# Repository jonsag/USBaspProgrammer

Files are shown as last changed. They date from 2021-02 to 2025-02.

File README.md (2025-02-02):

# USBaspProgrammer

My adaption of [Thomas Fischl's construction](https://www.fischl.de/usbasp/).  

This README concentrates on using ATmega88, and uploading it with avrisp, with a device such as [this one](https://github.com/jonsag/ardAVRProgrammer).  
Use the ICSP header on the programmer, and remember to set jumper J2.  

## Compile and upload

Put the ATmega88 in the programming device, and  

>$ cd Firmware/firmware

Test avrdude  

>$ make avrdude

    avrdude -c avrisp -p atmega88 -P /dev/ttyUSB0 -b 19200 -v

    avrdude: Version 6.3
            Copyright (c) 2000-2005 Brian Dean, http://www.bdmicro.com/
            Copyright (c) 2007-2014 Joerg Wunsch

            System wide configuration file is "/etc/avrdude.conf"
            User configuration file is "/home/jon/.avrduderc"
            User configuration file does not exist or is not a regular file, skipping

            Using Port                    : /dev/ttyUSB0
            Using Programmer              : avrisp
            Overriding Baud Rate          : 19200
            AVR Part                      : ATmega88
            Chip Erase delay              : 9000 us
            PAGEL                         : PD7
            BS2                           : PC2
            RESET disposition             : dedicated
            RETRY pulse                   : SCK
            serial program mode           : yes
            parallel program mode         : yes
            Timeout                       : 200
            StabDelay                     : 100
            CmdexeDelay                   : 25
            SyncLoops                     : 32
            ByteDelay                     : 0
            PollIndex                     : 3
            PollValue                     : 0x53
            Memory Detail                 :

                                    Block Poll               Page                       Polled
            Memory Type Mode Delay Size  Indx Paged  Size   Size #Pages MinW  MaxW   ReadBack
            ----------- ---- ----- ----- ---- ------ ------ ---- ------ ----- ----- ---------
            eeprom        65    20     4    0 no        512    4      0  3600  3600 0xff 0xff
            flash         65     6    64    0 yes      8192   64    128  4500  4500 0xff 0xff
            lfuse          0     0     0    0 no          1    0      0  4500  4500 0x00 0x00
            hfuse          0     0     0    0 no          1    0      0  4500  4500 0x00 0x00
            efuse          0     0     0    0 no          1    0      0  4500  4500 0x00 0x00
            lock           0     0     0    0 no          1    0      0  4500  4500 0x00 0x00
            calibration    0     0     0    0 no          1    0      0     0     0 0x00 0x00
            signature      0     0     0    0 no          3    0      0     0     0 0x00 0x00

            Programmer Type : STK500
            Description     : Atmel AVR ISP
            Hardware Version: 2
            Firmware Version: 1.18
            Topcard         : Unknown
            Vtarget         : 0.0 V
            Varef           : 0.0 V
            Oscillator      : Off
            SCK period      : 0.1 us

    avrdude: AVR device initialized and ready to accept instructions

    Reading | ################################################## | 100% 0.08s

    avrdude: Device signature = 0x1e930a (probably m88)
    avrdude: safemode: hfuse reads as DF
    avrdude: safemode: efuse reads as F9

    avrdude: safemode: hfuse reads as DF
    avrdude: safemode: efuse reads as F9
    avrdude: safemode: Fuses OK (E:F9, H:DF, L:62)

    avrdude done.  Thank you.

Clean, compile, upload and set fuses  

>$ make clean

    rm -f main.hex main.lst main.obj main.cof main.list main.map main.eep.hex main.bin *.o main.s usbdrv/*.o

>$ make main.hex

    avr-gcc -Wall -O2 -Iusbdrv -I. -mmcu=atmega88  -c usbdrv/usbdrv.c -o usbdrv/usbdrv.o
    avr-gcc -Wall -O2 -Iusbdrv -I. -mmcu=atmega88  -x assembler-with-cpp -c usbdrv/usbdrvasm.S -o usbdrv/usbdrvasm.o
    avr-gcc -Wall -O2 -Iusbdrv -I. -mmcu=atmega88  -c usbdrv/oddebug.c -o usbdrv/oddebug.o
    avr-gcc -Wall -O2 -Iusbdrv -I. -mmcu=atmega88  -c isp.c -o isp.o
    avr-gcc -Wall -O2 -Iusbdrv -I. -mmcu=atmega88  -c clock.c -o clock.o
    avr-gcc -Wall -O2 -Iusbdrv -I. -mmcu=atmega88  -x assembler-with-cpp -c tpi.S -o tpi.o
    avr-gcc -Wall -O2 -Iusbdrv -I. -mmcu=atmega88  -c main.c -o main.o
    avr-gcc -Wall -O2 -Iusbdrv -I. -mmcu=atmega88  -o main.bin usbdrv/usbdrv.o usbdrv/usbdrvasm.o usbdrv/oddebug.o isp.o clock.o tpi.o main.o -Wl,-Map,main.map
    rm -f main.hex main.eep.hex
    avr-objcopy -j .text -j .data -O ihex main.bin main.hex

>$ make flash

    avrdude -c avrisp -p atmega88 -P /dev/ttyUSB0 -b 19200 -U flash:w:main.hex

    avrdude: AVR device initialized and ready to accept instructions

    Reading | ################################################## | 100% 0.08s

    avrdude: Device signature = 0x1e930a (probably m88)
    avrdude: NOTE: "flash" memory has been specified, an erase cycle will be performed
            To disable this feature, specify the -D option.
    avrdude: erasing chip
    avrdude: reading input file "main.hex"
    avrdude: input file main.hex auto detected as Intel Hex
    avrdude: writing flash (4400 bytes):

    Writing | ################################################## | 100% 7.60s

    avrdude: 4400 bytes of flash written
    avrdude: verifying flash memory against main.hex:
    avrdude: load data flash data from input file main.hex:
    avrdude: input file main.hex auto detected as Intel Hex
    avrdude: input file main.hex contains 4400 bytes
    avrdude: reading on-chip flash data:

    Reading | ################################################## | 100% 5.38s

    avrdude: verifying ...
    avrdude: 4400 bytes of flash verified

    avrdude: safemode: Fuses OK (E:F9, H:DF, L:62)

    avrdude done.  Thank you.

>$ make fuses

    avrdude -c avrisp -p atmega88 -P /dev/ttyUSB0 -b 19200 -u -U hfuse:w:0xDD:m -U lfuse:w:0xFF:m

    avrdude: AVR device initialized and ready to accept instructions

    Reading | ################################################## | 100% 0.08s

    avrdude: Device signature = 0x1e930a (probably m88)
    avrdude: reading input file "0xDD"
    avrdude: writing hfuse (1 bytes):

    Writing | ################################################## | 100% 0.09s

    avrdude: 1 bytes of hfuse written
    avrdude: verifying hfuse memory against 0xDD:
    avrdude: load data hfuse data from input file 0xDD:
    avrdude: input file 0xDD contains 1 bytes
    avrdude: reading on-chip hfuse data:

    Reading | ################################################## | 100% 0.03s

    avrdude: verifying ...
    avrdude: 1 bytes of hfuse verified
    avrdude: reading input file "0xFF"
    avrdude: writing lfuse (1 bytes):

    Writing | ################################################## | 100% 0.09s

    avrdude: 1 bytes of lfuse written
    avrdude: verifying lfuse memory against 0xFF:
    avrdude: load data lfuse data from input file 0xFF:
    avrdude: input file 0xFF contains 1 bytes
    avrdude: reading on-chip lfuse data:

    Reading | ################################################## | 100% 0.03s

    avrdude: verifying ...
    avrdude: 1 bytes of lfuse verified

    avrdude done.  Thank you.

## Define device rules

>$ sudo cp \<PATH>/Documents/linux-nonroot/99-USBasp.rules /etc/udev/rules.d/99-USBasp.rules
>
>$ sudo udevadm control --reload-rules

## From Thomas Fischl's README

### USE PRECOMPILED VERSION  

Firmware:  
Flash "Firmware/precompiled/usbasp.atmega88.xxxx-xx-xx.hex" or "Firmware/precompiled/usbaspatmega8.xxxx-xx-xx.hex" to the used controller with a working programmer (e.g. with avrdude, uisp, ...). Set jumper J2 to activate USBasp firmware update function.  
You have to change the fuse bits for external crystal (see "make fuses").  
\# TARGET=atmega8    HFUSE=0xc9  LFUSE=0xef  
\# TARGET=atmega48   HFUSE=0xdd  LFUSE=0xff  
\# TARGET=atmega88   HFUSE=0xdd  LFUSE=0xff  

### Setting jumpers

J1 Power target  
    Supply target with 5V (USB voltage). Be careful with this option, the circuit isn't protected against short circuit!  
J2 Jumper for firmware upgrade (not self-upgradable)  
    Set this jumper for flashing the ATMega(4)8 of USBasp with another working programmer.  
J3 SCK option  
    If the target clock is lower than 1,5 MHz, you have to set this jumper. Then SCK is scaled down from 375 kHz to about 8 kHz  

### BUILDING AND INSTALLING FROM SOURCE CODE

#### Firmware

To compile the firmware  

1. install the GNU toolchain for AVR microcontrollers (avr-gcc, avr-libc),  
2. change directory to Firmware/firmware/  
3. run "make main.hex"  
4. flash "main.hex" to the ATMega(4)8. E.g. with uisp or avrdude (check the Makefile option "make flash"). To flash the firmware you have to set jumper J2 and connect USBasp to a working programmer.  
 You have to change the fuse bits for external crystal, (check the Makefile option "make fuses").  

#### Software (avrdude)

AVRDUDE supports USBasp since version 5.2.  

1. install libusb: [http://libusb.sourceforge.net/](http://libusb.sourceforge.net/)  
2. get latest avrdude release: [http://download.savannah.gnu.org/releases/avrdude/](http://download.savannah.gnu.org/releases/avrdude/)  
3. cd avrdude-X.X.X  
4. configure to your environment:  
./bootstrap (I had to comment out the two if-blocks which verify the installed versions of autoconf and automake)  
./configure  
5. compile and install it:  
make  
make install  

### Notes

To use USBasp as non-root, you have to define some device rules. See Documents/linux-nonroot for an example.  

### MORE INFORMATION

For more information on USBasp and it's components please visit the following URLs:  

USBasp .......................... [http://www.fischl.de/usbasp/](http://www.fischl.de/usbasp/)  
  
Firmware-only V-USB driver ...... [http://www.obdev.at/products/vusb/](http://www.obdev.at/products/vusb/)  
avrdude ......................... [http://www.nongnu.org/avrdude/](http://www.nongnu.org/avrdude/)  
libusb .......................... [http://libusb.sourceforge.net/](http://libusb.sourceforge.net/)  
libusb-win32 .................... [http://libusb-win32.sourceforge.net/](http://libusb-win32.sourceforge.net/)  

## Troubleshooting

### Compiling problem

    usbdrv/usbdrv.h:455:6: error: variable ‘usbDescriptorDevice’ must be const in order to be put into read-only section by means of ‘__attribute__((progmem))’
 char usbDescriptorDevice[];

Solution at [https://openrcforums.com/forum/viewtopic.php?t=2731](https://openrcforums.com/forum/viewtopic.php?t=2731), from Mon Feb 04, 2013  

    This issue is resolved I just wanted to document it here.

    Usbasp uses V-usb for usb communications. Usbasp includes V-usb in it's source code. The version of V-usb included in Usbasp is not the latest and would not compile with a recent avr-gcc. This issue affected er9x over a year ago.

    When trying to compile the 2009 or 2011 versions of Usbasp from http://www.fischl.de/usbasp/ I got about a dozen of these errors.
    CODE: SELECT ALL

    usbdrv/usbdrv.h:451:6: error: variable ‘usbDescriptorDevice’ must be const in order to be put into read-only section by means of ‘__attribute__((progmem))’
    The solution was to remove the ./firmware/usbdrv directory from the Usbasp source and replace it with the source from http://www.obdev.at/downloads/vusb/vusb-20121206.tar.gz . Then I was able to compile Usbasp. I tested both the 2009 and 2011 versions on a programmer and was able to program a MCU.

    Not sure when avr-gcc became picky about this issue or if that is even the issue. Nor do I know why my Ubuntuish 'Linux Mint 14 Nadia' calls the package gcc-avr. Anyway this is what versions of the relevant ( I think) packages I have installed.

    ii avr-libc 1:1.8.0-2 all Standard C library for Atmel AVR developm
    ii binutils-avr 2.20.1-3 amd64 Binary utilities supporting Atmel's AVR t
    ii gcc-avr 1:4.7.0-2 amd64 The GNU C compiler (cross compiler for av

## My notes

Connections on different MCUs  

            10Pin           6pin    ATmega8/88/328/328P     ATtiny4313      ATtiny85  
MOSI    ->  1           ->  4   ->  17/PB3                  17/PB5          5/AREF/PB0  
MISO    ->  9           ->  1   ->  18/PB4                  18/PB6          6/PB1  
SCK     ->  7           ->  3   ->  19/PB5                  19/PB7          7/PB2  
RST     ->  5           ->  5   ->  1/RESET/PC6,21/AREF     1/RESET/PA2     1/RESET/PB5  
VCC     ->  2           ->  2   ->  7/VCC                   20/VCC          8/VCC  
GND     ->  4,6,8,10    ->  6   ->  8/GND                   10/GND          4/GND  
XTAL1                               9/XTAL1                 5/XTAL1         2/XTAL1
XTAL2                               10/XTAL2                4/XTAL2         3/XTAL2

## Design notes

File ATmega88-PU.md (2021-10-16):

# Dissection of the ATmega88-PU

## Empty chip

>$ cu -l /dev/ttyACM0 -s 115200

    Atmega chip detector.
    Written by Nick Gammon.
    Version 1.20
    Compiled on Feb 15 2021 at 16:17:48 with Arduino IDE 10813.
    Attempting to enter ICSP programming mode ...
    Entered programming mode OK.
    Signature = 0x1E 0x93 0x0A 
    Unrecognized signature.
    LFuse = 0x62 
    HFuse = 0xDF 
    EFuse = 0xF9 
    Lock byte = 0xFF 
    Clock calibration = 0xAB 

    First 256 bytes of program memory:

    00: 0xFF 0xFF 0xFF 0xFF 0xFF 0xFF 0xFF 0xFF 0xFF 0xFF 0xFF 0xFF 0xFF 0xFF 0xFF 0xFF
    ...
    F0: 0xFF 0xFF 0xFF 0xFF 0xFF 0xFF 0xFF 0xFF 0xFF 0xFF 0xFF 0xFF 0xFF 0xFF 0xFF 0xFF 

    Programming mode off.

Dumping flash and eeprom  

>$ avrdude -p m88 -P /dev/ttyUSB0 -c avrisp -b 19200 -v -U flash:r:flashEmpty.hex:i -U eeprom:r:eepromEmpty.eep:i

    avrdude: Version 6.3
            Copyright (c) 2000-2005 Brian Dean, http://www.bdmicro.com/
            Copyright (c) 2007-2014 Joerg Wunsch

            System wide configuration file is "/etc/avrdude.conf"
            User configuration file is "/home/jon/.avrduderc"
            User configuration file does not exist or is not a regular file, skipping

            Using Port                    : /dev/ttyUSB0
            Using Programmer              : avrisp
            Overriding Baud Rate          : 19200
            AVR Part                      : ATmega88
            Chip Erase delay              : 9000 us
            PAGEL                         : PD7
            BS2                           : PC2
            RESET disposition             : dedicated
            RETRY pulse                   : SCK
            serial program mode           : yes
            parallel program mode         : yes
            Timeout                       : 200
            StabDelay                     : 100
            CmdexeDelay                   : 25
            SyncLoops                     : 32
            ByteDelay                     : 0
            PollIndex                     : 3
            PollValue                     : 0x53
            Memory Detail                 :

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

            Programmer Type : STK500
            Description     : Atmel AVR ISP
            Hardware Version: 2
            Firmware Version: 1.18
            Topcard         : Unknown
            Vtarget         : 0.0 V
            Varef           : 0.0 V
            Oscillator      : Off
            SCK period      : 0.1 us

    avrdude: AVR device initialized and ready to accept instructions

    Reading | ################################################## | 100% 0.08s

    avrdude: Device signature = 0x1e930a (probably m88)
    avrdude: safemode: hfuse reads as DF
    avrdude: safemode: efuse reads as F9
    avrdude: reading flash memory:

    Reading | ################################################## | 100% 9.97s

    avrdude: Flash is empty, resulting file has no contents.
    avrdude: writing output file "flashEmpty.hex"
    avrdude: reading eeprom memory:

    Reading | ################################################## | 100% 7.88s

    avrdude: writing output file "eepromEmpty.eep"

    avrdude: safemode: hfuse reads as DF
    avrdude: safemode: efuse reads as F9
    avrdude: safemode: Fuses OK (E:F9, H:DF, L:62)

    avrdude done.  Thank you.

Read fuses  

>$ avrdude -p m88 -P /dev/ttyUSB0 -c avrisp -b 19200 -U lfuse:r:-:i -U hfuse:r:-:i -U efuse:r:-:i

    avrdude: AVR device initialized and ready to accept instructions

    Reading | ################################################## | 100% 0.08s

    avrdude: Device signature = 0x1e930a (probably m88)
    avrdude: reading lfuse memory:

    Reading | ################################################## | 100% 0.03s

    avrdude: writing output file "<stdout>"
    :01000000629D
    :00000001FF
    avrdude: reading hfuse memory:

    Reading | ################################################## | 100% 0.03s

    avrdude: writing output file "<stdout>"
    :01000000DF20
    :00000001FF
    avrdude: reading efuse memory:

    Reading | ################################################## | 100% 0.04s

    avrdude: writing output file "<stdout>"
    :01000000F906
    :00000001FF

    avrdude: safemode: Fuses OK (E:F9, H:DF, L:62)

    avrdude done.  Thank you.

All three confirms fuses are  

    LFuse = 0x62 
    HFuse = 0xDF 
    EFuse = 0xF9 

Lock byte  

    Lock byte = 0xFF

Clock calibration  

    Clock calibration = 0xAB

## After programming

>$ cu -l /dev/ttyACM0 -s 115200

    Atmega chip detector.
    Written by Nick Gammon.
    Version 1.20
    Compiled on Feb 15 2021 at 16:17:48 with Arduino IDE 10813.
    Attempting to enter ICSP programming mode ...
    Entered programming mode OK.
    Signature = 0x1E 0x93 0x0A 
    Unrecognized signature.
    LFuse = 0xFF 
    HFuse = 0xDD 
    EFuse = 0xF9 
    Lock byte = 0xFF 
    Clock calibration = 0xAB 

    First 256 bytes of program memory:

    00: 0x42 0xC0 0xAA 0xC1 0x5B 0xC0 0x5A 0xC0 0x59 0xC0 0x58 0xC0 0x57 0xC0 0x56 0xC0 
    ...
    F0: 0x10 0x92 0x28 0x01 0x80 0x91 0x01 0x01 0x84 0xFF 0x3A 0xC0 0xC0 0x91 0x00 0x01 

    Programming mode off.

Dumping flash and eeprom  

>$ avrdude -p m88 -P /dev/ttyUSB0 -c avrisp -b 19200 -v -U flash:r:flashProgrammed.hex:i -U eeprom:r:eepromProgrammed.eep:i

    avrdude: Version 6.3
            Copyright (c) 2000-2005 Brian Dean, http://www.bdmicro.com/
            Copyright (c) 2007-2014 Joerg Wunsch

            System wide configuration file is "/etc/avrdude.conf"
            User configuration file is "/home/jon/.avrduderc"
            User configuration file does not exist or is not a regular file, skipping

            Using Port                    : /dev/ttyUSB0
            Using Programmer              : avrisp
            Overriding Baud Rate          : 19200
            AVR Part                      : ATmega88
            Chip Erase delay              : 9000 us
            PAGEL                         : PD7
            BS2                           : PC2
            RESET disposition             : dedicated
            RETRY pulse                   : SCK
            serial program mode           : yes
            parallel program mode         : yes
            Timeout                       : 200
            StabDelay                     : 100
            CmdexeDelay                   : 25
            SyncLoops                     : 32
            ByteDelay                     : 0
            PollIndex                     : 3
            PollValue                     : 0x53
            Memory Detail                 :

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

            Programmer Type : STK500
            Description     : Atmel AVR ISP
            Hardware Version: 2
            Firmware Version: 1.18
            Topcard         : Unknown
            Vtarget         : 0.0 V
            Varef           : 0.0 V
            Oscillator      : Off
            SCK period      : 0.1 us

    avrdude: AVR device initialized and ready to accept instructions

    Reading | ################################################## | 100% 0.08s

    avrdude: Device signature = 0x1e930a (probably m88)
    avrdude: safemode: hfuse reads as DD
    avrdude: safemode: efuse reads as F9
    avrdude: reading flash memory:

    Reading | ################################################## | 100% 9.97s

    avrdude: writing output file "flashProgrammed.hex"
    avrdude: reading eeprom memory:

    Reading | ################################################## | 100% 7.90s

    avrdude: writing output file "eepromProgrammed.eep"

    avrdude: safemode: hfuse reads as DD
    avrdude: safemode: efuse reads as F9
    avrdude: safemode: Fuses OK (E:F9, H:DD, L:FF)

    avrdude done.  Thank you.

Read fuses  

>$ avrdude -p m88 -P /dev/ttyUSB0 -c avrisp -b 19200 -U lfuse:r:-:i -U hfuse:r:-:i -U efuse:r:-:i

    avrdude: AVR device initialized and ready to accept instructions

    Reading | ################################################## | 100% 0.08s

    avrdude: Device signature = 0x1e930a (probably m88)
    avrdude: reading lfuse memory:

    Reading | ################################################## | 100% 0.03s

    avrdude: writing output file "<stdout>"
    :01000000FF00
    :00000001FF
    avrdude: reading hfuse memory:

    Reading | ################################################## | 100% 0.03s

    avrdude: writing output file "<stdout>"
    :01000000DD22
    :00000001FF
    avrdude: reading efuse memory:

    Reading | ################################################## | 100% 0.03s

    avrdude: writing output file "<stdout>"
    :01000000F906
    :00000001FF

    avrdude: safemode: Fuses OK (E:F9, H:DD, L:FF)

    avrdude done.  Thank you.

All three agrees on fuses  

    LFuse = 0xFF 
    HFuse = 0xDD 
    EFuse = 0xF9 

Lock byte still  

    Lock byte = 0xFF 

Clock calibration is now  

    Clock calibration = 0xAB

Diff  

>$ diff main.hex flashProgrammed.hex | wc -l

    418

## Testing the programmer

Insert programmer  

>$ dmesg

    ...
    [173324.477738] usb 4-4: new low-speed USB device number 32 using ohci-pci
    [173324.722745] usb 4-4: New USB device found, idVendor=16c0, idProduct=05dc, bcdDevice= 1.04
    [173324.722749] usb 4-4: New USB device strings: Mfr=1, Product=2, SerialNumber=0
    [173324.722752] usb 4-4: Product: USBasp
    [173324.722754] usb 4-4: Manufacturer: www.fischl.de

>$ lsusb

    ...
    Bus 004 Device 036: ID 16c0:05dc Van Ooijen Technische Informatica shared ID for use with libusb
    ...

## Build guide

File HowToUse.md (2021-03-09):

# How to use the programmer

Check  

>$ avrdude -p m328p -c usbasp -v

Read flash  

>$ avrdude -p m328p -c usbasp -v -U flash:r:flash.hex:i

Verify flash  

>$ avrdude -p m328p -c usbasp -v -U flash:v:flash.hex:i

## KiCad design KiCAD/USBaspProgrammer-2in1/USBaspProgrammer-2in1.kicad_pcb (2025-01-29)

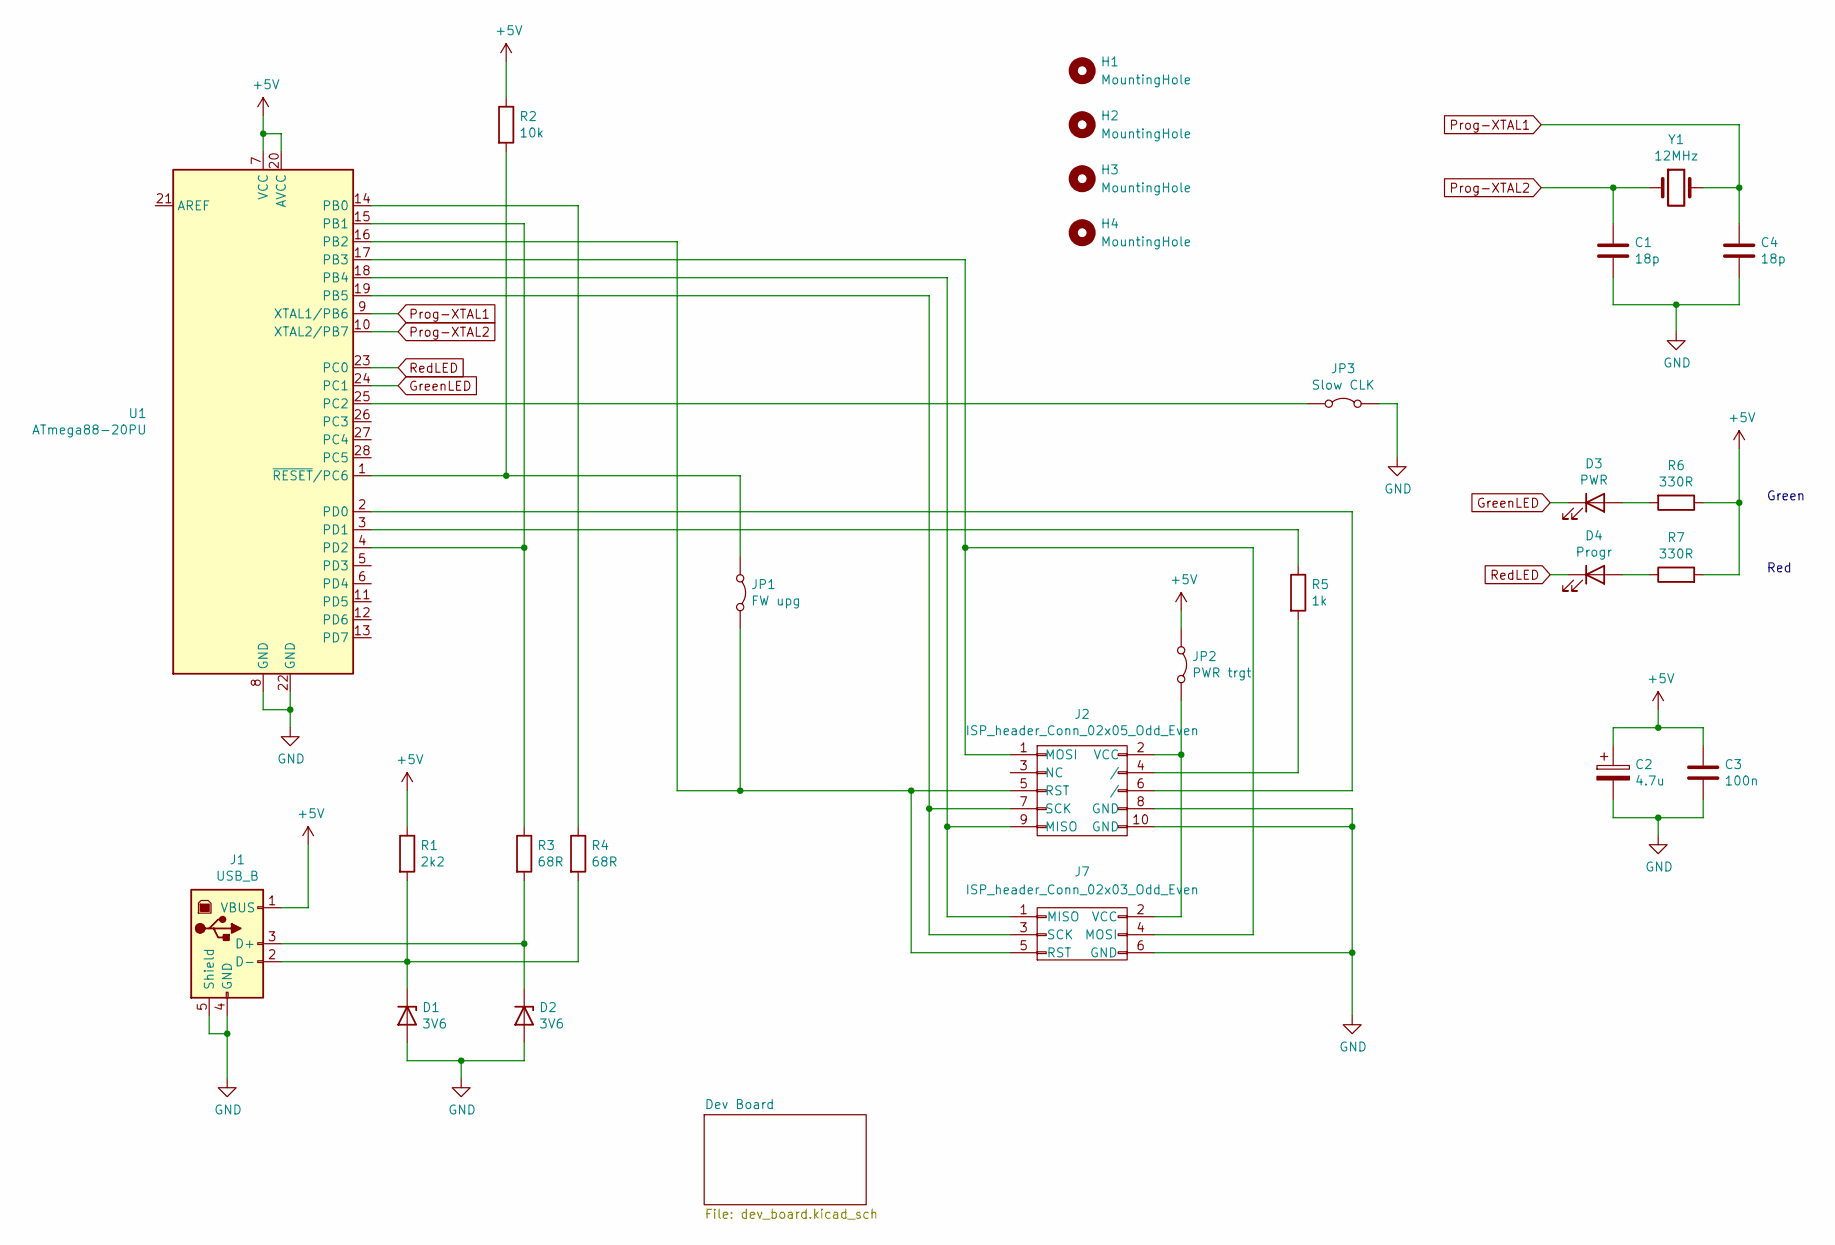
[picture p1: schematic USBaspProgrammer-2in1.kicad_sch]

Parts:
C1, C4: 18p; C_Disc_D3.0mm_W1.6mm_P2.50mm_larg
C2: 4.7u; CP_Radial_D5.0mm_P2.00mm_larger
C3: 100n; C_Disc_D7.5mm_W2.5mm_P5.00mm_larger
D1, D2: 3V6; D_DO-35_SOD27_P7.62mm_Horizontal_large
D3: PWR; LED_D5.0mm_larger_pads
D4: Progr; LED_D5.0mm_larger_pads
H1, H2, H3, H4: MountingHole; MountingHole_3.2mm_M3
J1: USB_B; USB_B_OST_USB-B1HSxx_Horizontal_large
J2: ISP_header_Conn_02x05_Odd_Even; IDC-Header_2x05_P2.54mm_Vertical_large
J7: ISP_header_Conn_02x03_Odd_Even; IDC-Header_2x03_P2.54mm_Horizontal_large
JP1: FW upg; Jumper_1x02_P2.54mm_large
JP2: PWR trgt; Jumper_1x02_P2.54mm_large
JP3: Slow CLK; Jumper_1x02_P2.54mm_large
R1: 2k2; R_Axial_DIN0207_L6.3mm_D2.5mm_P10.16mm_Horizontal_large
R2: 10k; R_Axial_DIN0207_L6.3mm_D2.5mm_P10.16mm_Horizontal_large
R3, R4: 68R; R_Axial_DIN0207_L6.3mm_D2.5mm_P10.16mm_Horizontal_large
R5: 1k; R_Axial_DIN0207_L6.3mm_D2.5mm_P10.16mm_Horizontal_large
R6, R7: 330R; R_Axial_DIN0207_L6.3mm_D2.5mm_P10.16mm_Horizontal_large
U1: ATmega88-20PU; DIP-28_W7.62mm_LongPads w socket
Y1: 12MHz; Crystal_HC49-4H_Vertical_large

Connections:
+5V: C2.1, C3.1, J1.1 (VBUS), JP2.1 (A), R1.1, R2.1, R6.1, R7.2, U1.7 (VCC), U1.20 (AVCC)
GND: C1.2, C2.2, C3.2, C4.2, D1.2 (A), D2.2 (A), J1.4 (GND), J1.5 (Shield), J2.8 (GND), J2.10 (GND), J7.6 (GND), JP3.2 (B), U1.8 (GND), U1.22 (GND); also elsewhere on the board
GreenLED: D3.1 (K), U1.24 (PC1)
unnamed: D1.1 (K), J1.2 (D-), R1.2, R4.2
unnamed: D2.1 (K), J1.3 (D+), R3.2
unnamed: D3.2 (A), R6.2
unnamed: D4.2 (A), R7.1
unnamed: J2.9 (MISO), J7.1 (MISO), U1.18 (PB4)
unnamed: J2.1 (MOSI), J7.4 (MOSI), U1.17 (PB3)
unnamed: J2.5 (RST), J7.5 (RST), JP1.2 (B), U1.16 (PB2)
unnamed: J2.7 (SCK), J7.3 (SCK), U1.19 (PB5)
unnamed: J2.2 (VCC), J7.2 (VCC), JP2.2 (B)
unnamed: J2.4 (/), R5.2
unnamed: JP1.1 (A), R2.2, U1.1 (~RESET/PC6)
unnamed: JP3.1 (A), U1.25 (PC2)
unnamed: R4.1, U1.14 (PB0)
unnamed: R3.1, U1.4 (PD2), U1.15 (PB1)
unnamed: J2.6 (/), U1.2 (PD0)
unnamed: R5.1, U1.3 (PD1)
Prog-XTAL1: C4.1, U1.9 (XTAL1/PB6), Y1.2
Prog-XTAL2: C1.1, U1.10 (XTAL2/PB7), Y1.1
RedLED: D4.1 (K), U1.23 (PC0)

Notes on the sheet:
Green
Red

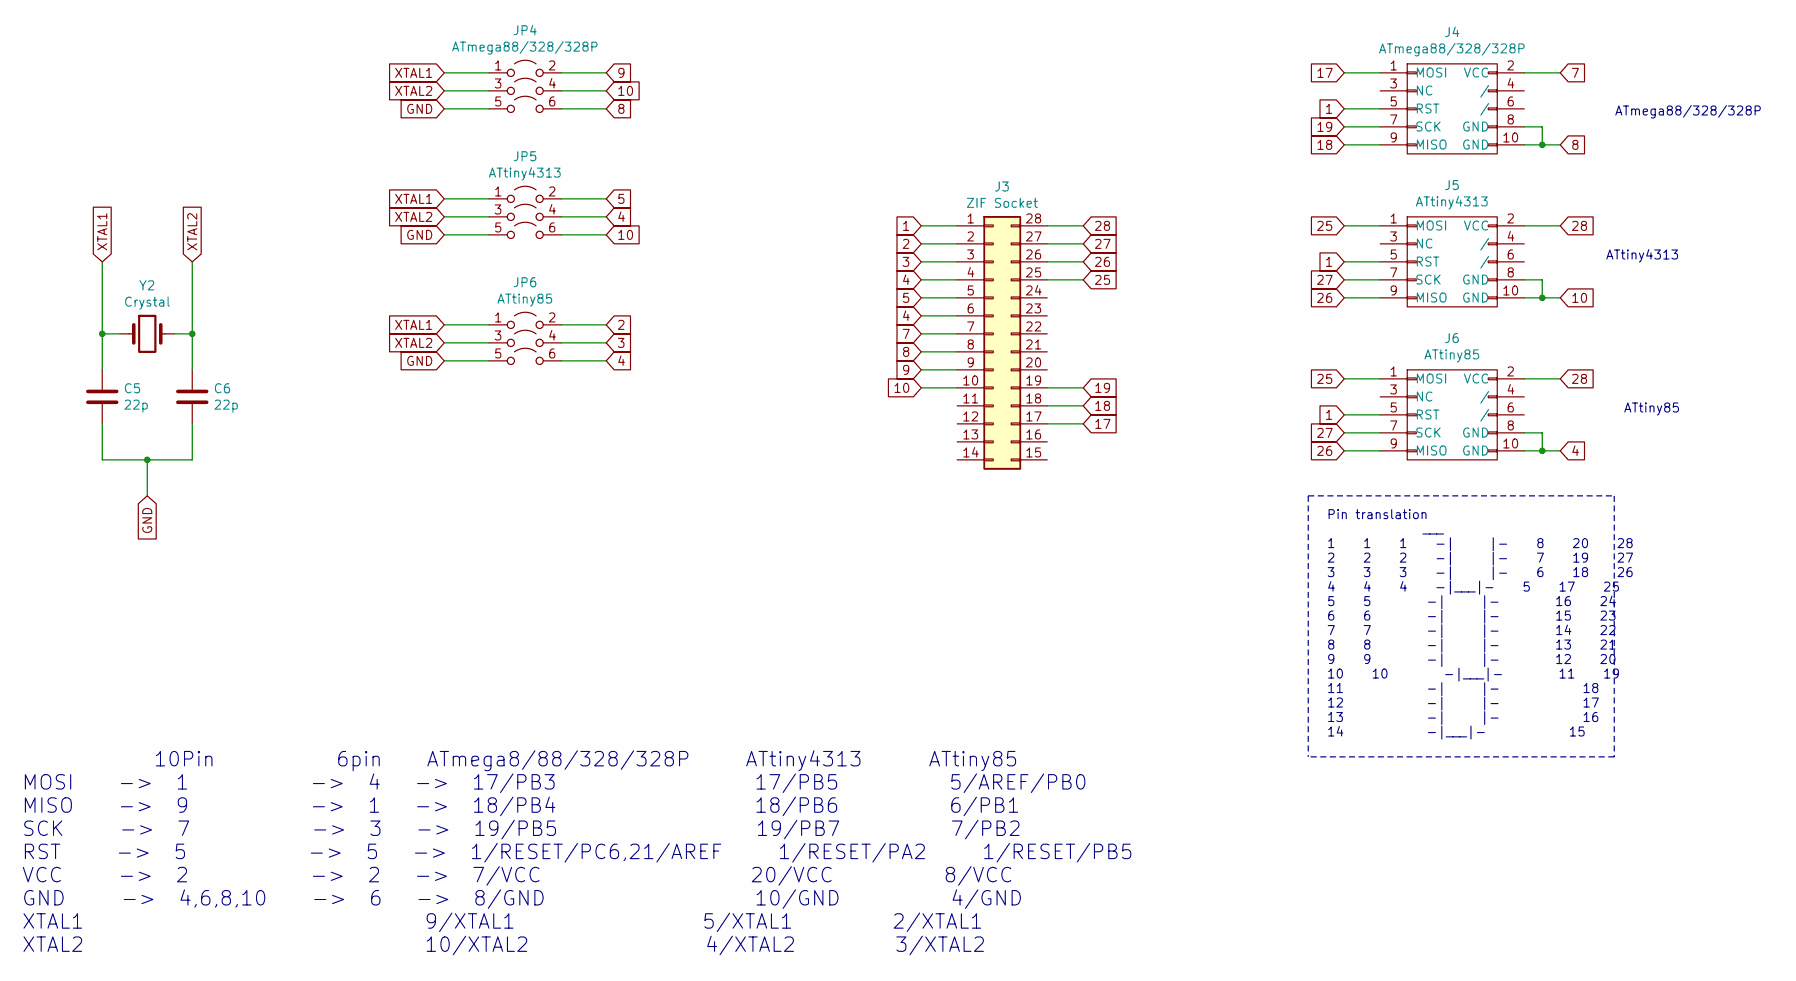
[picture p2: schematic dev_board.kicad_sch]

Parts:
C5, C6: 22p; C_Disc_D3.0mm_W1.6mm_P2.50mm_larg
J3: ZIF Socket; ZIF_DIP_Socket-28_W6.9_W7.62_W7.62_W12.7_W13.5_large
J4: ATmega88/328/328P; IDC-Header_2x05_P2.54mm_Vertical_large
J5: ATtiny4313; IDC-Header_2x05_P2.54mm_Vertical_large
J6: ATtiny85; IDC-Header_2x05_P2.54mm_Vertical_large
JP4: ATmega88/328/328P; 3-pole_jumper_2x03_P2.54mm_Vertical
JP5: ATtiny4313; 3-pole_jumper_2x03_P2.54mm_Vertical
JP6: ATtiny85; 3-pole_jumper_2x03_P2.54mm_Vertical
Y2: Crystal; Crystal_HC49-4H_Vertical_large

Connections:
1: J3.1, J4.5 (RST), J5.5 (RST), J6.5 (RST)
2: J3.2, JP6.2 (B)
3: J3.3, JP6.4
4: J3.4, J3.6, J6.8 (GND), J6.10 (GND), JP5.4, JP6.6
5: J3.5, JP5.2 (B)
7: J3.7, J4.2 (VCC)
8: J3.8, J4.8 (GND), J4.10 (GND), JP4.6
9: J3.9, JP4.2 (B)
10: J3.10, J5.8 (GND), J5.10 (GND), JP4.4, JP5.6
17: J3.17, J4.1 (MOSI)
18: J3.18, J4.9 (MISO)
19: J3.19, J4.7 (SCK)
25: J3.25, J5.1 (MOSI), J6.1 (MOSI)
26: J3.26, J5.9 (MISO), J6.9 (MISO)
27: J3.27, J5.7 (SCK), J6.7 (SCK)
28: J3.28, J5.2 (VCC), J6.2 (VCC)
GND: C5.2, C6.2, JP4.5, JP5.5, JP6.5; also elsewhere on the board
XTAL1: C5.1, JP4.1 (A), JP5.1 (A), JP6.1 (A), Y2.1
XTAL2: C6.1, JP4.3, JP5.3, JP6.3, Y2.2

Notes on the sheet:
ATtiny85
Pin translation ___ 1 1 1 -| |- 8 20 28 2 2 2 -| |- 7 19 27 3 3 3 -| |- 6 18 26 4 4 4 -|___|- 5 17 25 5 5 -| |- 16 24 6 6 -| |- 15 23 7 7 -| |- 14 22 8 8 -| |- 13 21 9 9 -| |- 12 20 10 10 -|___|- 11 19 11 -| |- 18 12 -| |- 17 13 -| |- 16 14 -|___|- 15
ATmega88/328/328P
10Pin 6pin ATmega8/88/328/328P ATtiny4313 ATtiny85 MOSI -> 1 -> 4 -> 17/PB3 17/PB5 5/AREF/PB0 MISO -> 9 -> 1 -> 18/PB4 18/PB6 6/PB1 SCK -> 7 -> 3 -> 19/PB5 19/PB7 7/PB2 RST -> 5 -> 5 -> 1/RESET/PC6,21/AREF 1/RESET/PA2 1/RESET/PB5 VCC -> 2 -> 2 -> 7/VCC 20/VCC 8/VCC GND -> 4,6,8,10 -> 6 -> 8/GND 10/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
ATtiny4313

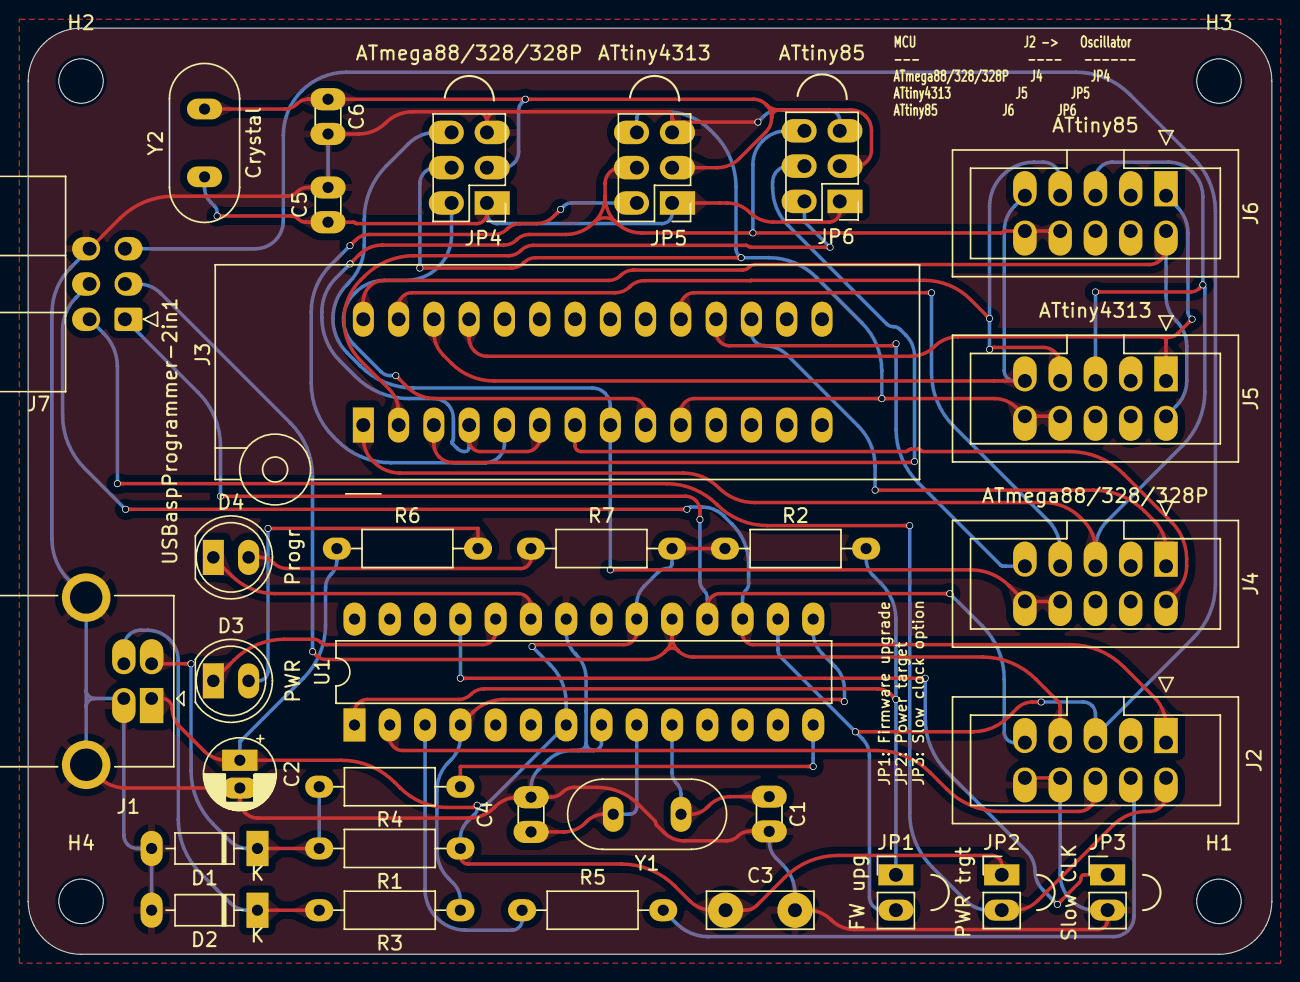
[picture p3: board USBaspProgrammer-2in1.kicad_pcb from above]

Board: 2 copper layers, 89.5 x 66.7 mm, 37 parts (0 on the bottom side), 40 nets.

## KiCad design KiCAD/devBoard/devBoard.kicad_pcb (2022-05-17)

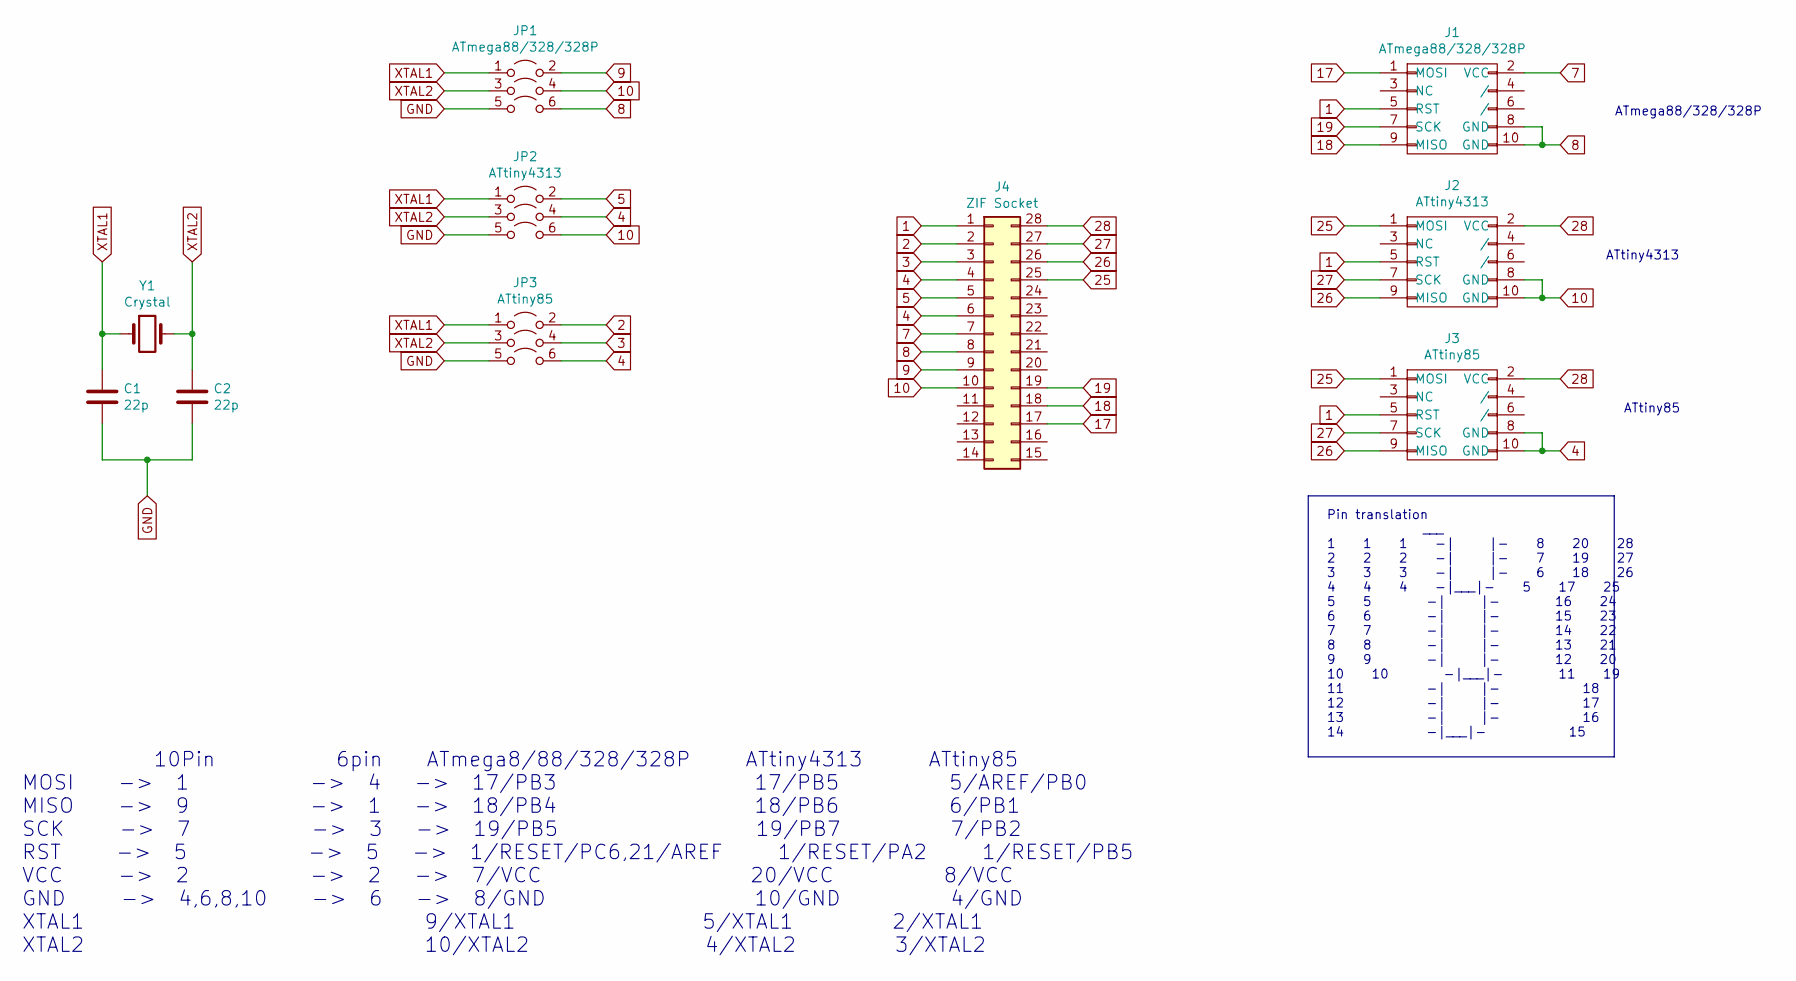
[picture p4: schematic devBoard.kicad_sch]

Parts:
C1, C2: 22p; C_Disc_D3.0mm_W1.6mm_P2.50mm_larg
J1: ATmega88/328/328P; IDC-Header_2x05_P2.54mm_Vertical_large
J2: ATtiny4313; IDC-Header_2x05_P2.54mm_Vertical_large
J3: ATtiny85; IDC-Header_2x05_P2.54mm_Vertical_large
J4: ZIF Socket; ZIF_DIP_Socket-28_W6.9_W7.62_W7.62_W12.7_W13.5_large
JP1: ATmega88/328/328P; 3-pole_jumper_2x03_P2.54mm_Vertical
JP2: ATtiny4313; 3-pole_jumper_2x03_P2.54mm_Vertical
JP3: ATtiny85; 3-pole_jumper_2x03_P2.54mm_Vertical
Y1: Crystal; 2-pin_Crystal_header_large

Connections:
1: J1.5 (RST), J2.5 (RST), J3.5 (RST), J4.1
2: J4.2, JP3.2 (B)
3: J4.3, JP3.4
4: J3.8 (GND), J3.10 (GND), J4.4, J4.6, JP2.4, JP3.6
5: J4.5, JP2.2 (B)
7: J1.2 (VCC), J4.7
8: J1.8 (GND), J1.10 (GND), J4.8, JP1.6
9: J4.9, JP1.2 (B)
10: J2.8 (GND), J2.10 (GND), J4.10, JP1.4, JP2.6
17: J1.1 (MOSI), J4.17
18: J1.9 (MISO), J4.18
19: J1.7 (SCK), J4.19
25: J2.1 (MOSI), J3.1 (MOSI), J4.25
26: J2.9 (MISO), J3.9 (MISO), J4.26
27: J2.7 (SCK), J3.7 (SCK), J4.27
28: J2.2 (VCC), J3.2 (VCC), J4.28
GND: C1.2, C2.2, JP1.5, JP2.5, JP3.5
XTAL1: C1.1, JP1.1 (A), JP2.1 (A), JP3.1 (A), Y1.1
XTAL2: C2.1, JP1.3, JP2.3, JP3.3, Y1.2

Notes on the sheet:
ATtiny4313
ATmega88/328/328P
ATtiny85
Pin translation ___ 1 1 1 -| |- 8 20 28 2 2 2 -| |- 7 19 27 3 3 3 -| |- 6 18 26 4 4 4 -|___|- 5 17 25 5 5 -| |- 16 24 6 6 -| |- 15 23 7 7 -| |- 14 22 8 8 -| |- 13 21 9 9 -| |- 12 20 10 10 -|___|- 11 19 11 -| |- 18 12 -| |- 17 13 -| |- 16 14 -|___|- 15
10Pin 6pin ATmega8/88/328/328P ATtiny4313 ATtiny85 MOSI -> 1 -> 4 -> 17/PB3 17/PB5 5/AREF/PB0 MISO -> 9 -> 1 -> 18/PB4 18/PB6 6/PB1 SCK -> 7 -> 3 -> 19/PB5 19/PB7 7/PB2 RST -> 5 -> 5 -> 1/RESET/PC6,21/AREF 1/RESET/PA2 1/RESET/PB5 VCC -> 2 -> 2 -> 7/VCC 20/VCC 8/VCC GND -> 4,6,8,10 -> 6 -> 8/GND 10/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

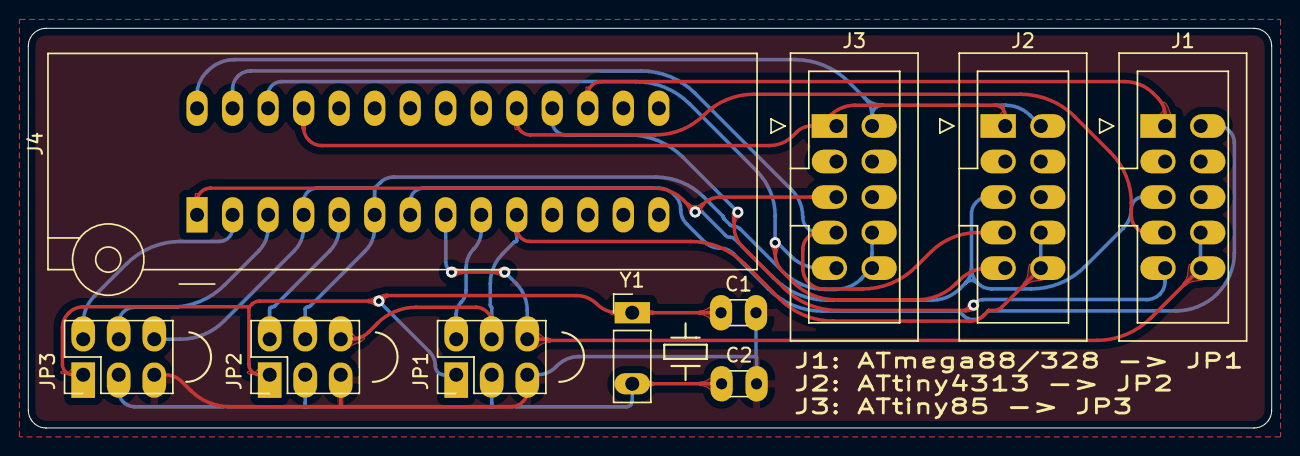
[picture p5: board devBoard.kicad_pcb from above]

Board: 2 copper layers, 88.9 x 28.6 mm, 10 parts (0 on the bottom side), 19 nets.

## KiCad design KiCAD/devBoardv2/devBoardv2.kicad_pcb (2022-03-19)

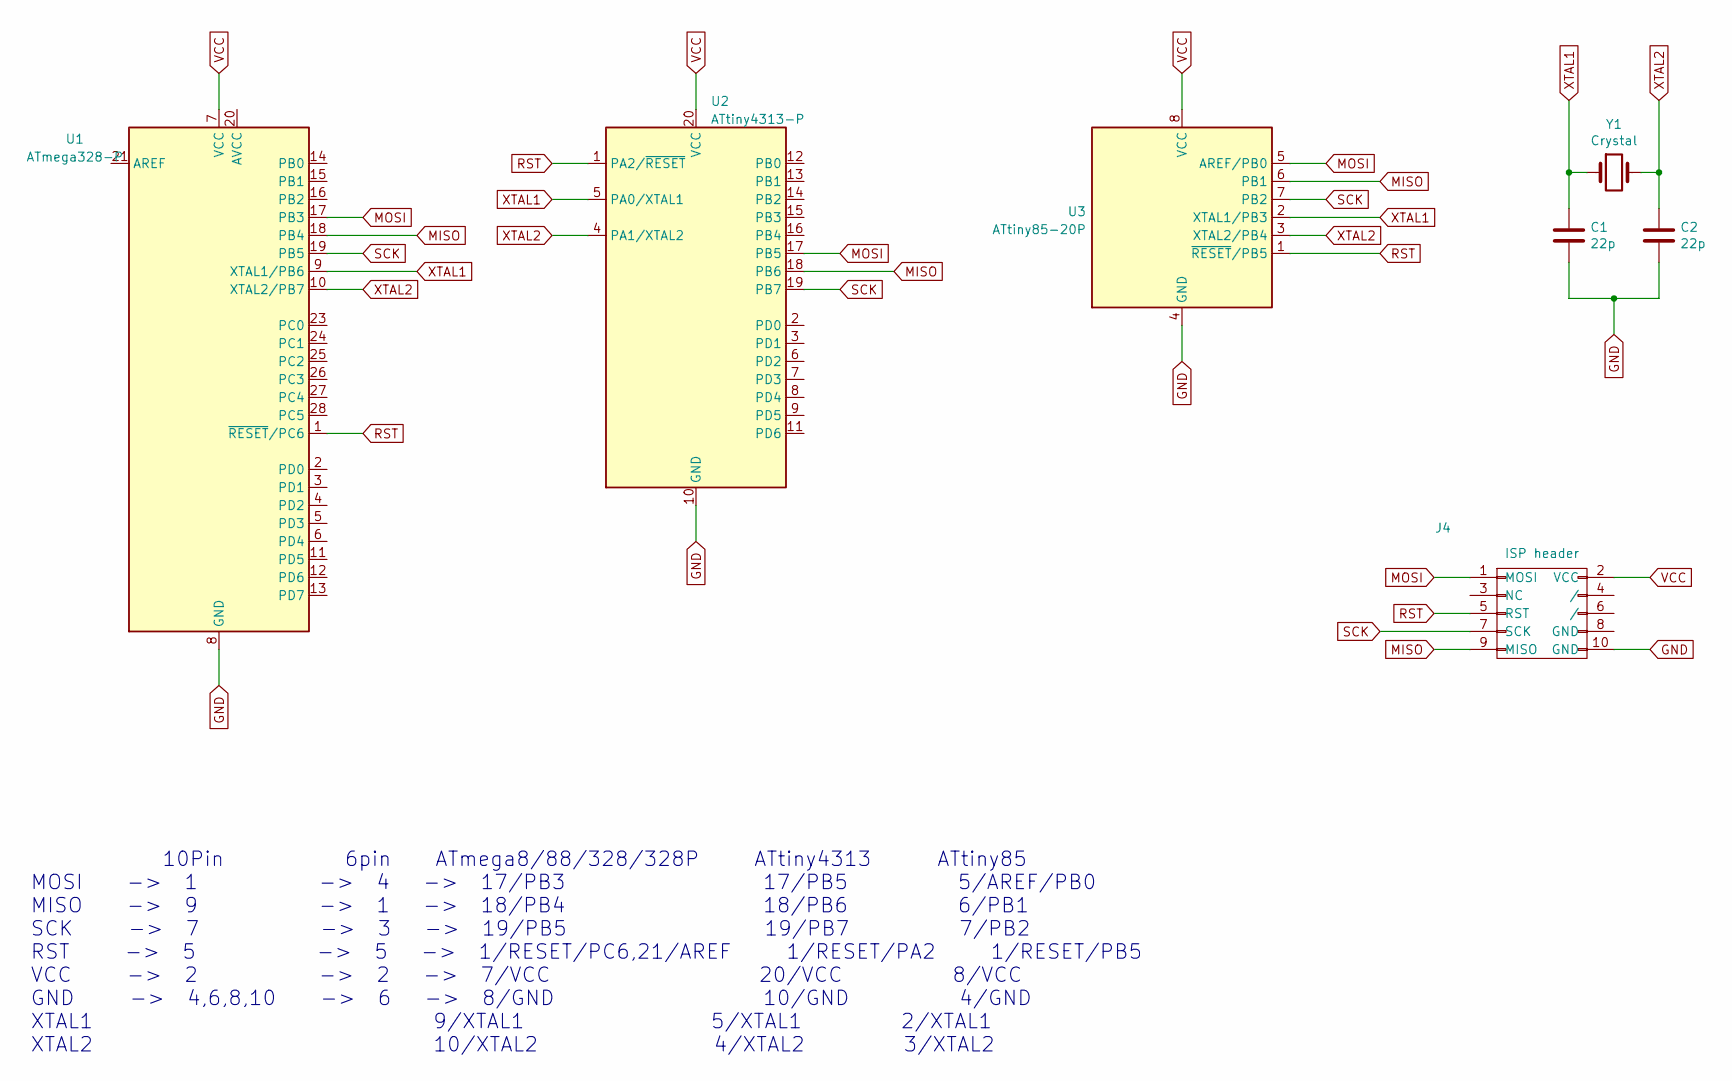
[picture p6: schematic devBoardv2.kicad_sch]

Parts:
C1, C2: 22p; C_Disc_D3.0mm_W1.6mm_P2.50mm_larg
J4: ISP header; IDC-Header_2x05_P2.54mm_Vertical_large
U1: ATmega328-P
U2: ATtiny4313-P
U3: ATtiny85-20P
Y1: Crystal; 2-pin_Crystal_header_large

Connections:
GND: C1.2, C2.2, J4.10 (GND), U1.8 (GND), U1.22 (GND), U2.10 (GND), U3.4 (GND)
MISO: J4.9 (MISO), U1.18 (PB4), U2.18 (PB6), U3.6 (PB1)
MOSI: J4.1 (MOSI), U1.17 (PB3), U2.17 (PB5), U3.5 (AREF/PB0)
RST: J4.5 (RST), U1.1 (~RESET/PC6), U2.1 (PA2/~RESET), U3.1 (~RESET/PB5)
SCK: J4.7 (SCK), U1.19 (PB5), U2.19 (PB7), U3.7 (PB2)
VCC: J4.2 (VCC), U1.7 (VCC), U2.20 (VCC), U3.8 (VCC)
XTAL1: C1.1, U1.9 (XTAL1/PB6), U2.5 (PA0/XTAL1), U3.2 (XTAL1/PB3), Y1.1
XTAL2: C2.1, U1.10 (XTAL2/PB7), U2.4 (PA1/XTAL2), U3.3 (XTAL2/PB4), Y1.2

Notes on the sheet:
10Pin 6pin ATmega8/88/328/328P ATtiny4313 ATtiny85 MOSI -> 1 -> 4 -> 17/PB3 17/PB5 5/AREF/PB0 MISO -> 9 -> 1 -> 18/PB4 18/PB6 6/PB1 SCK -> 7 -> 3 -> 19/PB5 19/PB7 7/PB2 RST -> 5 -> 5 -> 1/RESET/PC6,21/AREF 1/RESET/PA2 1/RESET/PB5 VCC -> 2 -> 2 -> 7/VCC 20/VCC 8/VCC GND -> 4,6,8,10 -> 6 -> 8/GND 10/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

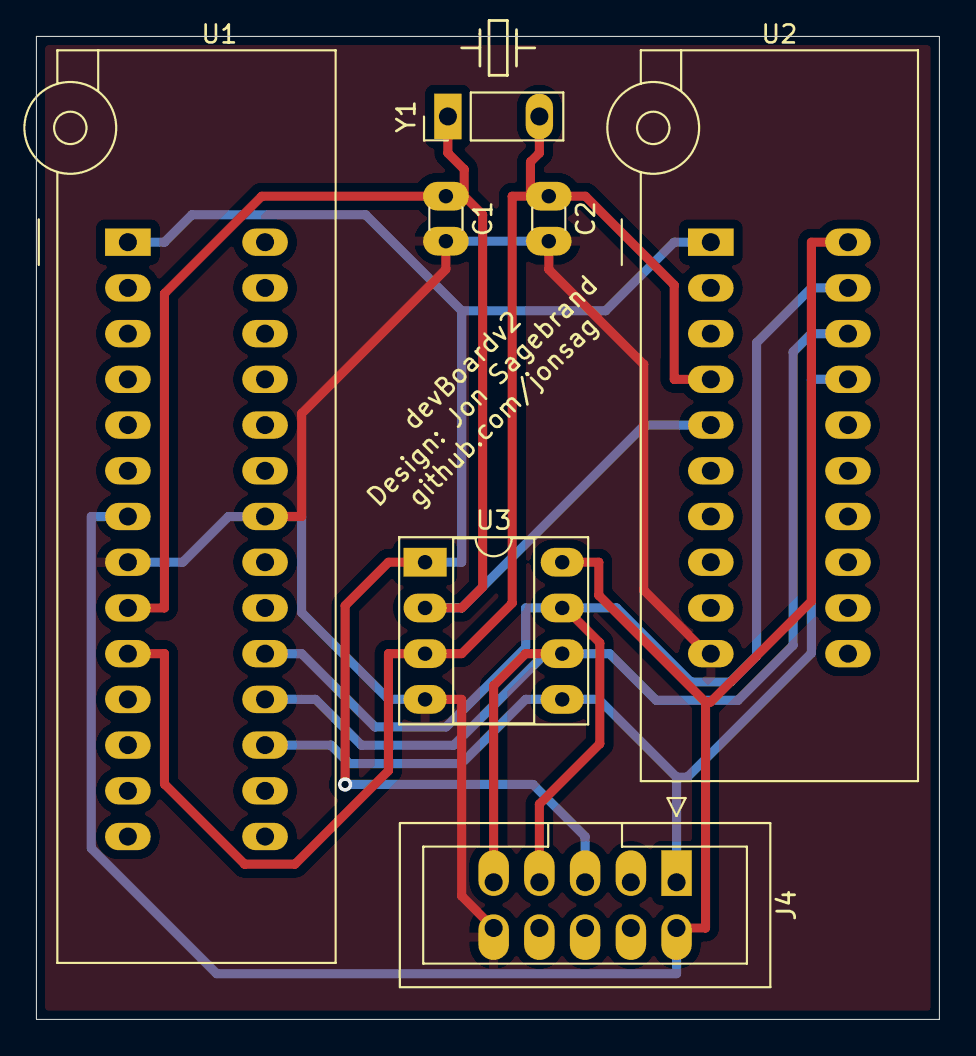
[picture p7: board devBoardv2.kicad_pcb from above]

Board: 2 copper layers, 50.2 x 54.6 mm, 7 parts (0 on the bottom side), 8 nets.

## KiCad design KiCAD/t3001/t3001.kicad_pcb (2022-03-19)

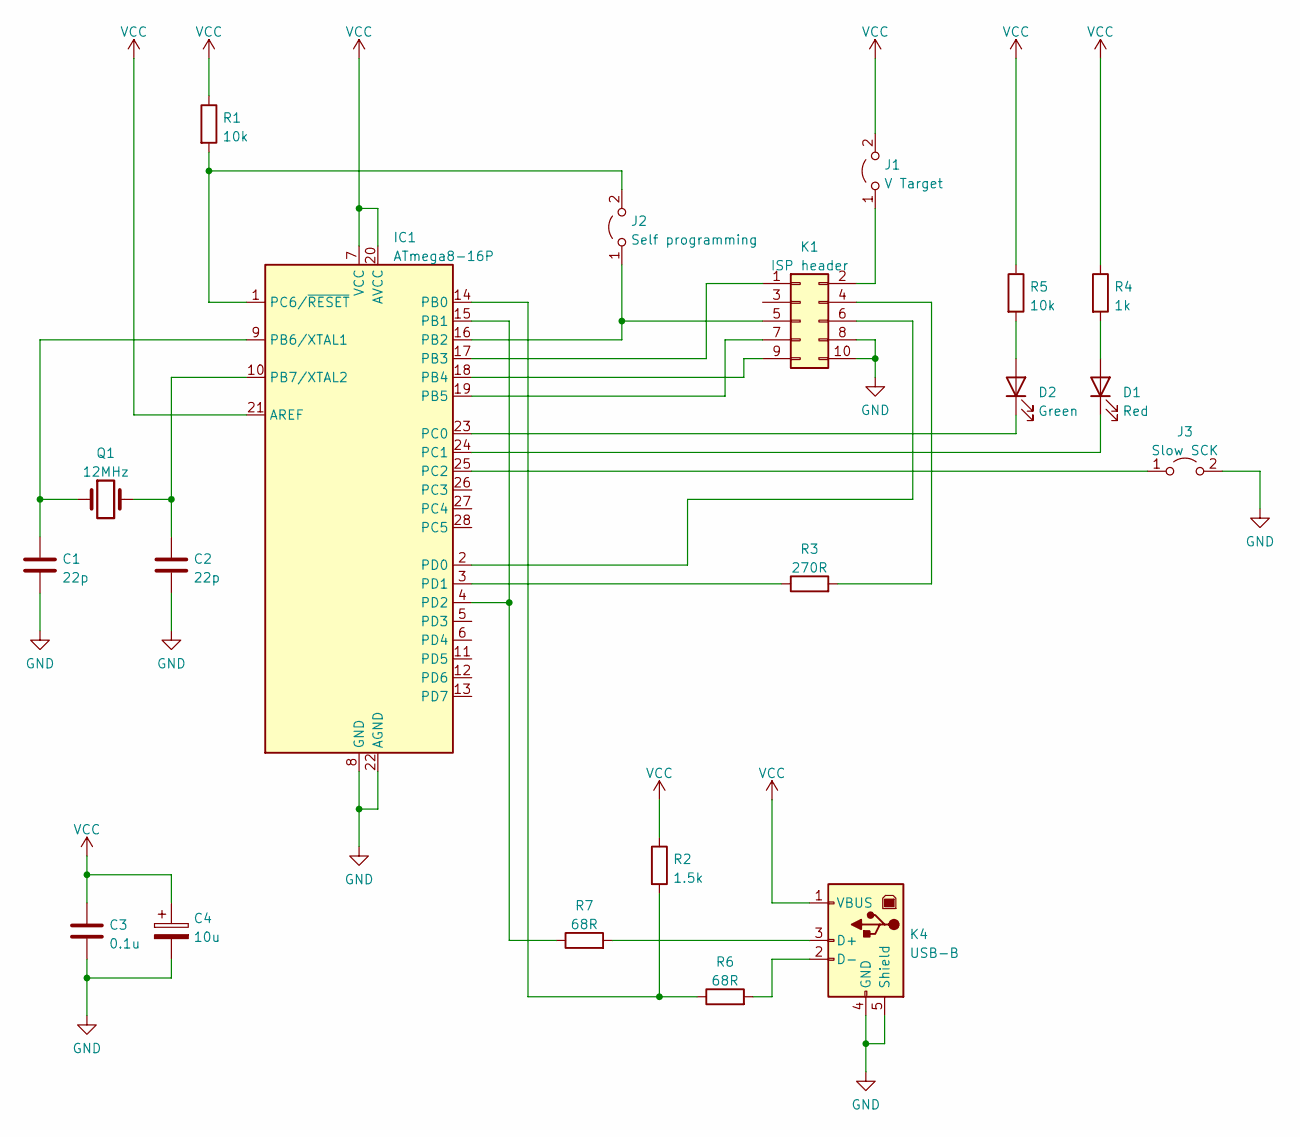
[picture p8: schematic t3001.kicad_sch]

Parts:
C1, C2: 22p; C_Disc_D3.0mm_W1.6mm_P2.50mm_larg
C3: 0.1u; C_Disc_D3.0mm_W1.6mm_P2.50mm_larg
C4: 10u; CP_Radial_D5.0mm_P2.50mm_larger_pads
D1: Red; LED_D5.0mm_larger_pads
D2: Green; LED_D5.0mm_larger_pads
IC1: ATmega8-16P; DIP-28_W7.62mm_LongPads
J1: V Target; Jumper_1x02_P2.54mm_large
J2: Self programming; Jumper_1x02_P2.54mm_large
J3: Slow SCK; Jumper_1x02_P2.54mm_large
K1: ISP header; 2x5_ISP_header_large
K4: USB-B; USB_B_OST_USB-B1HSxx_Horizontal_large
Q1: 12MHz; Crystal_HC49-4H_Vertical_large
R1, R5: 10k; R_Axial_DIN0207_L6.3mm_D2.5mm_P10.16mm_Horizontal_larger_pa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
R2: 1.5k; R_Axial_DIN0207_L6.3mm_D2.5mm_P10.16mm_Horizontal_larger_pa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
R3: 270R; R_Axial_DIN0207_L6.3mm_D2.5mm_P10.16mm_Horizontal_larger_pa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
R4: 1k; R_Axial_DIN0207_L6.3mm_D2.5mm_P10.16mm_Horizontal_larger_pa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
R6, R7: 68R; R_Axial_DIN0207_L6.3mm_D2.5mm_P10.16mm_Horizontal_larger_pa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

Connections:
GND: C1.2, C2.2, C3.2, C4.2, IC1.8 (GND), IC1.22 (AGND), J3.2 (B), K1.8, K1.10, K4.4 (GND), K4.5 (Shield)
unnamed: C1.1, IC1.9 (PB6/XTAL1), Q1.1
unnamed: C2.1, IC1.10 (PB7/XTAL2), Q1.2
unnamed: D1.1 (K), IC1.24 (PC1)
unnamed: D1.2 (A), R4.2
unnamed: D2.1 (K), IC1.23 (PC0)
unnamed: D2.2 (A), R5.2
unnamed: IC1.1 (PC6/~RESET), J2.2 (B), R1.2
unnamed: IC1.2 (PD0), K1.6
unnamed: IC1.3 (PD1), R3.1
unnamed: IC1.14 (PB0), R2.2, R6.1
unnamed: IC1.4 (PD2), IC1.15 (PB1), R7.1
unnamed: IC1.16 (PB2), J2.1 (A), K1.5
unnamed: IC1.17 (PB3), K1.1
unnamed: IC1.18 (PB4), K1.9
unnamed: IC1.19 (PB5), K1.7
unnamed: IC1.25 (PC2), J3.1 (A)
unnamed: J1.1 (A), K1.2
unnamed: K1.4, R3.2
unnamed: K4.2 (D-), R6.2
unnamed: K4.3 (D+), R7.2
VCC: C3.1, C4.1, IC1.7 (VCC), IC1.20 (AVCC), IC1.21 (AREF), J1.2 (B), K4.1 (VBUS), R1.1, R2.1, R4.1, R5.1

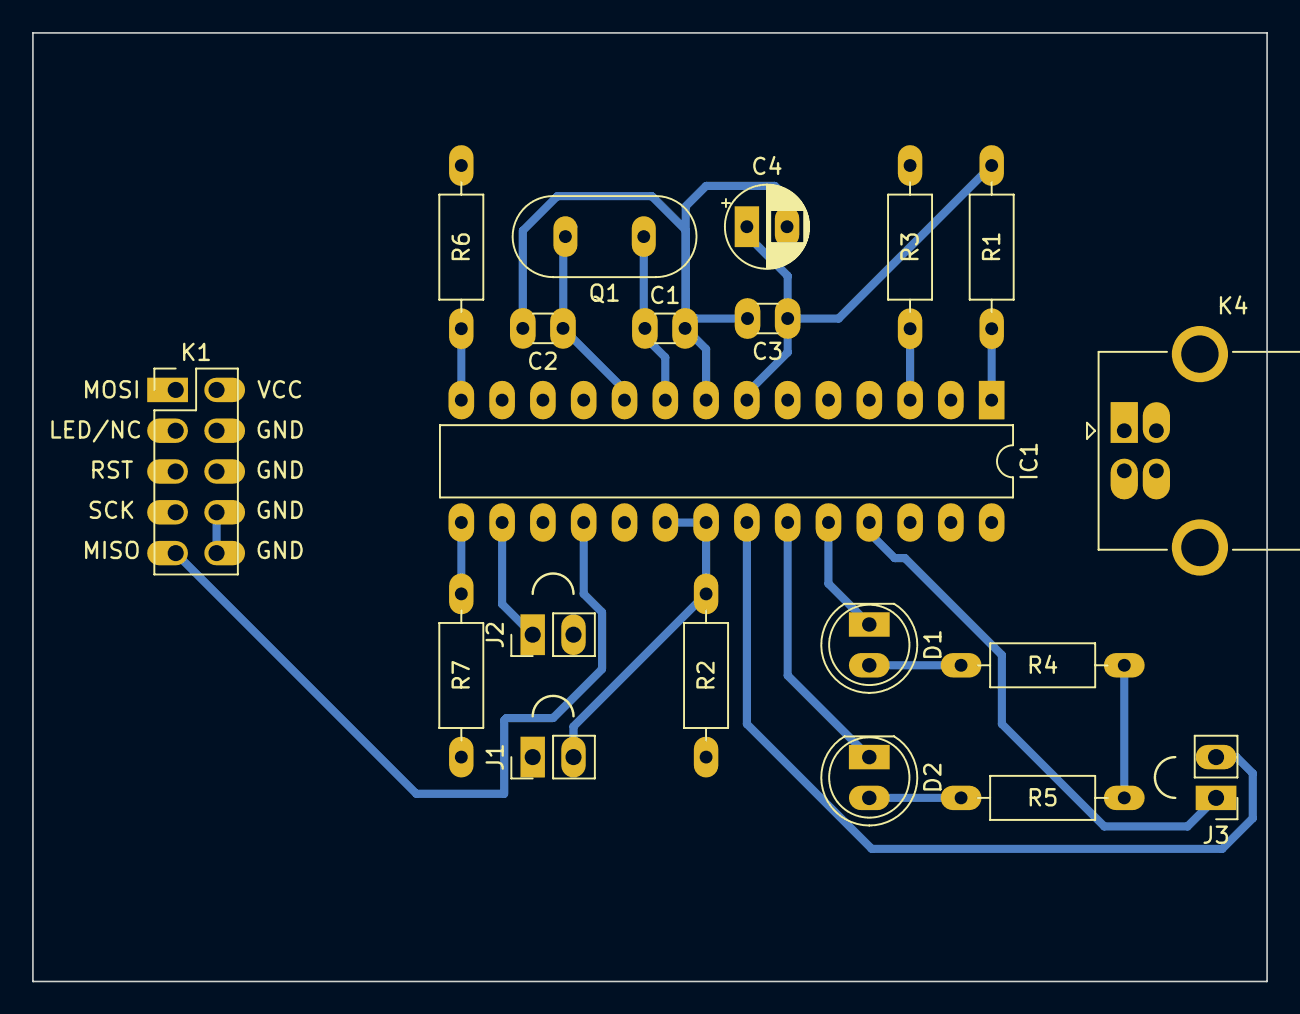
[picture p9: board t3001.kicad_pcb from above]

Board: 2 copper layers, 76.8 x 59.1 mm, 20 parts (0 on the bottom side), 22 nets.

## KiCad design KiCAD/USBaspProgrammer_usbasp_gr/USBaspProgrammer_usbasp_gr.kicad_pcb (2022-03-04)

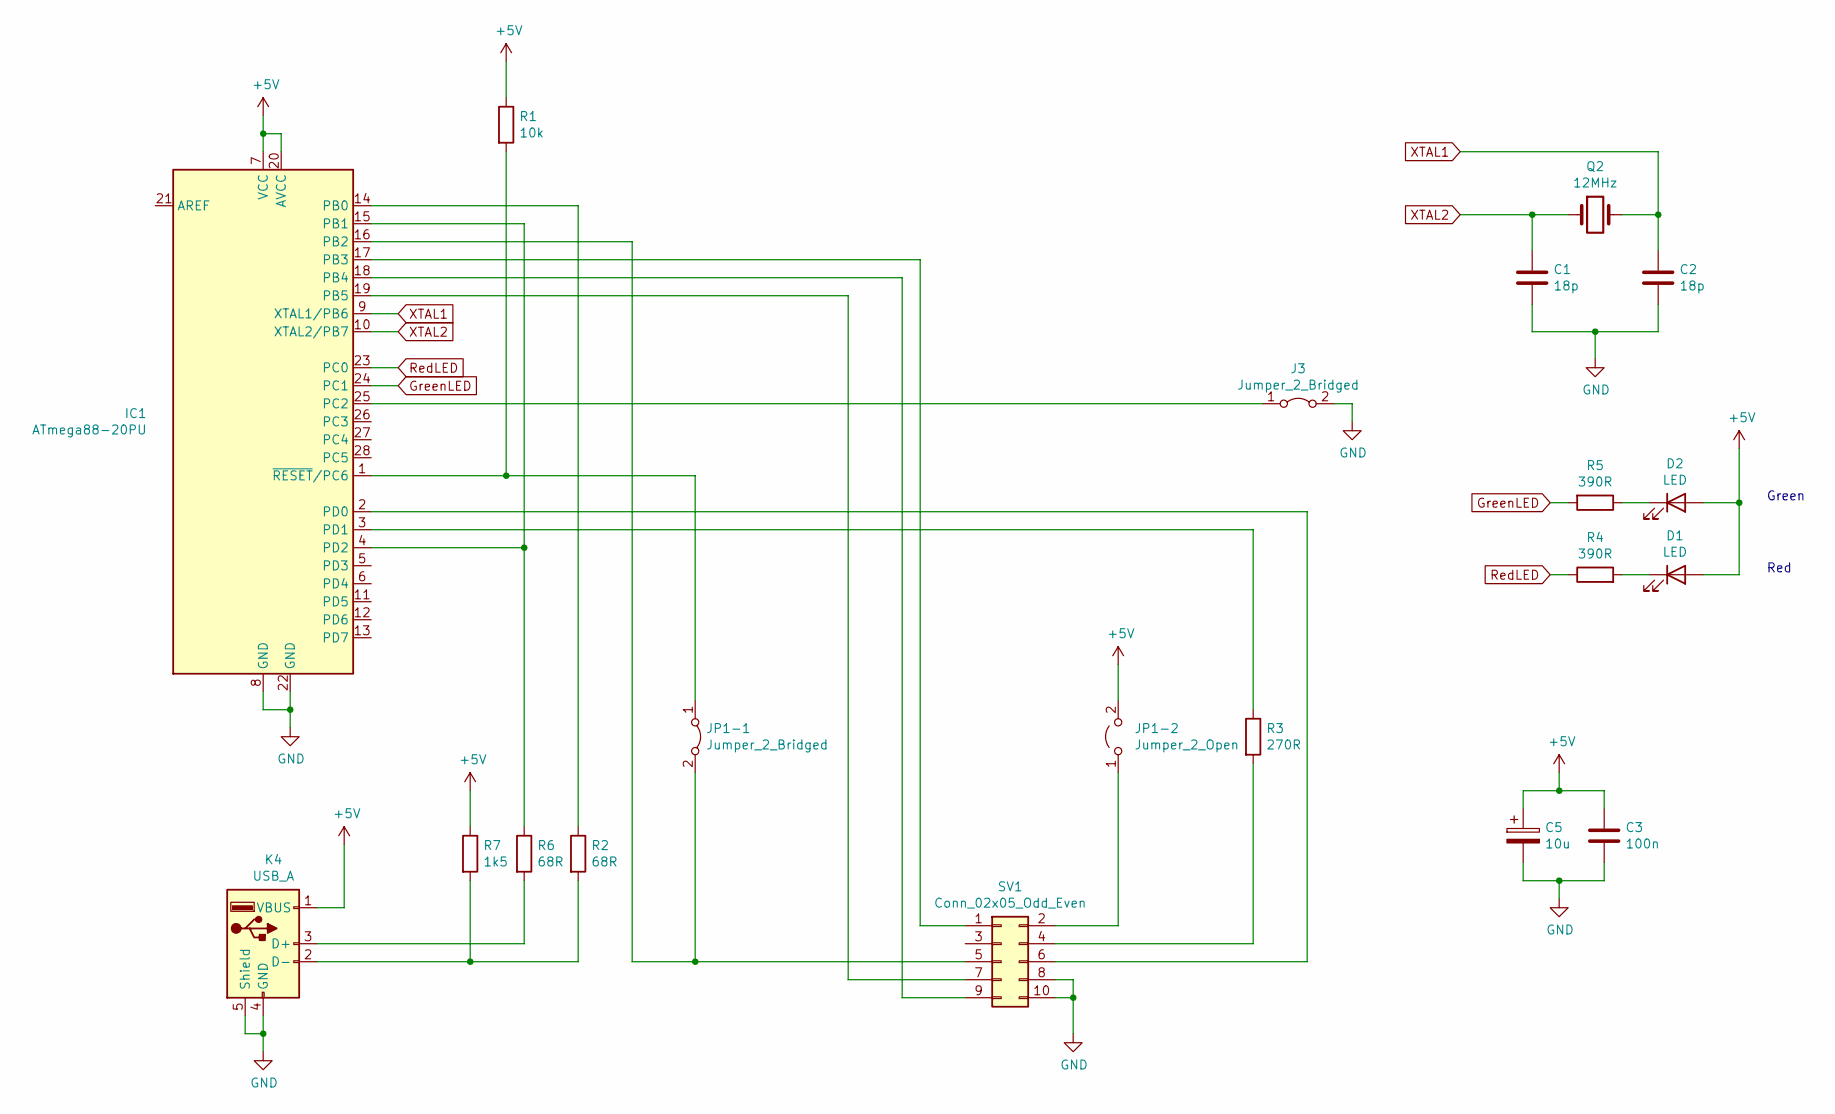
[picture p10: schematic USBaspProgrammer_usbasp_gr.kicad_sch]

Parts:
C1, C2: 18p; C_Disc_D3.0mm_W1.6mm_P2.50mm_larg
C3: 100n; C_Disc_D7.5mm_W2.5mm_P5.00mm_larger
C5: 10u; CP_Radial_D5.0mm_P2.00mm_larger
D1, D2: LED; LED_D5.0mm_larger_pads
IC1: ATmega88-20PU; DIP-28_W7.62mm_LongPads
J3: Jumper_2_Bridged; Jumper_1x02_P2.54mm_large
JP1-1: Jumper_2_Bridged; Jumper_1x02_P2.54mm_large
JP1-2: Jumper_2_Open; Jumper_1x02_P2.54mm_large
K4: USB_A; USB_B_Lumberg_2411_02_Horizontal_large
Q2: 12MHz; Crystal_HC49-4H_Vertical_large
R1: 10k; R_Axial_DIN0207_L6.3mm_D2.5mm_P10.16mm_Horizontal_larger_pa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
R2, R6: 68R; R_Axial_DIN0207_L6.3mm_D2.5mm_P10.16mm_Horizontal_larger_pa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
R3: 270R; R_Axial_DIN0207_L6.3mm_D2.5mm_P10.16mm_Horizontal_larger_pa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
R4, R5: 390R; R_Axial_DIN0207_L6.3mm_D2.5mm_P10.16mm_Horizontal_larger_pa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
R7: 1k5; R_Axial_DIN0207_L6.3mm_D2.5mm_P10.16mm_Horizontal_larger_pa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
SV1: Conn_02x05_Odd_Even; IDC-Header_2x05_P2.54mm_Vertical_large

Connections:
+5V: C3.1, C5.1, D1.2 (A), D2.2 (A), IC1.7 (VCC), IC1.20 (AVCC), JP1-2.2 (B), K4.1 (VBUS), R1.1, R7.1
GND: C1.2, C2.2, C3.2, C5.2, IC1.8 (GND), IC1.22 (GND), J3.2 (B), K4.4 (GND), K4.5 (Shield), SV1.8, SV1.10
GreenLED: IC1.24 (PC1), R5.2
unnamed: D1.1 (K), R4.2
unnamed: D2.1 (K), R5.1
unnamed: IC1.1 (~RESET/PC6), JP1-1.1 (A), R1.2
unnamed: IC1.2 (PD0), SV1.6
unnamed: IC1.3 (PD1), R3.1
unnamed: IC1.14 (PB0), R2.1
unnamed: IC1.4 (PD2), IC1.15 (PB1), R6.1
unnamed: IC1.16 (PB2), JP1-1.2 (B), SV1.5
unnamed: IC1.17 (PB3), SV1.1
unnamed: IC1.18 (PB4), SV1.9
unnamed: IC1.19 (PB5), SV1.7
unnamed: IC1.25 (PC2), J3.1 (A)
unnamed: JP1-2.1 (A), SV1.2
unnamed: K4.2 (D-), R2.2, R7.2
unnamed: K4.3 (D+), R6.2
unnamed: R3.2, SV1.4
RedLED: IC1.23 (PC0), R4.1
XTAL1: C2.1, IC1.9 (XTAL1/PB6), Q2.2
XTAL2: C1.1, IC1.10 (XTAL2/PB7), Q2.1

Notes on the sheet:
Green
Red

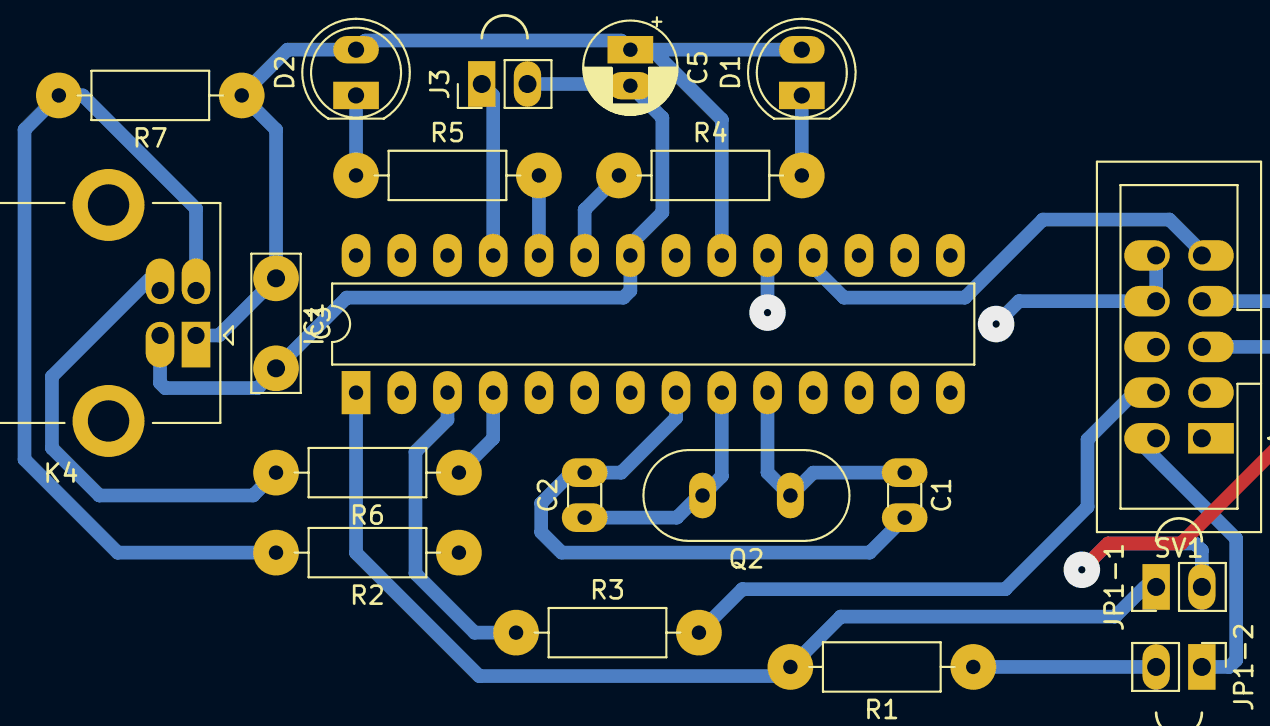
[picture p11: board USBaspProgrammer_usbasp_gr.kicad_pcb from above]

Board: 2 copper layers, 20 parts (0 on the bottom side), 22 nets.

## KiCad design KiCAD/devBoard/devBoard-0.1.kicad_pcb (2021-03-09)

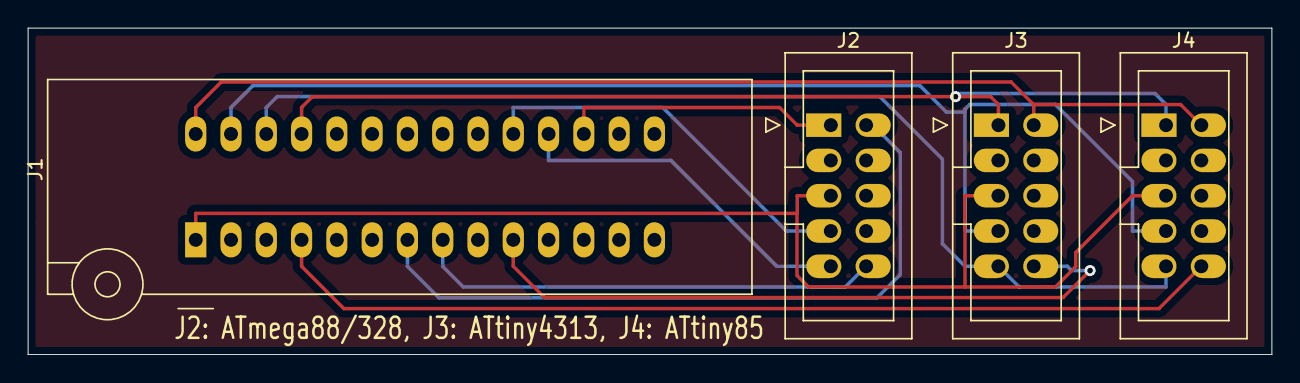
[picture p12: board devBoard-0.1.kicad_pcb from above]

Board: 2 copper layers, 89.5 x 23.5 mm, 4 parts (0 on the bottom side), 12 nets.

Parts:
J1: Conn_02x14_Counter_Clockwise; ZIF_DIP_Socket-28_W6.9_W7.62_W7.62_W12.7_W13.5_large
J2, J3, J4: ISP_header_Conn_02x05_Odd_Even; IDC-Header_2x05_P2.54mm_Vertical_large

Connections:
1: J1.1, J2.5, J3.5, J4.5
4: J1.4, J4.10
7: J1.7, J2.2
8: J1.8, J2.10
10: J1.10, J3.10
17: J1.17, J2.1
18: J1.18, J2.9
19: J1.19, J2.7
25: J1.25, J3.1, J4.1
26: J1.26, J3.9, J4.9
27: J1.27, J3.7, J4.7
28: J1.28, J3.2, J4.2

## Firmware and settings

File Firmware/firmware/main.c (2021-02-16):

/*
 * USBasp - USB in-circuit programmer for Atmel AVR controllers
 *
 * Thomas Fischl <tfischl@gmx.de>
 *
 * License........: GNU GPL v2 (see Readme.txt)
 * Target.........: ATMega8 at 12 MHz
 * Creation Date..: 2005-02-20
 * Last change....: 2009-02-28
 *
 * PC2 SCK speed option.
 * GND  -> slow (8khz SCK),
 * open -> software set speed (default is 375kHz SCK)
 */

#include <avr/io.h>
#include <avr/interrupt.h>
#include <avr/pgmspace.h>
#include <avr/wdt.h>

#include "usbasp.h"
#include "usbdrv.h"
#include "isp.h"
#include "clock.h"
#include "tpi.h"
#include "tpi_defs.h"

static uchar replyBuffer[8];

static uchar prog_state = PROG_STATE_IDLE;
static uchar prog_sck = USBASP_ISP_SCK_AUTO;

static uchar prog_address_newmode = 0;
static unsigned long prog_address;
static unsigned int prog_nbytes = 0;
static unsigned int prog_pagesize;
static uchar prog_blockflags;
static uchar prog_pagecounter;

uchar usbFunctionSetup(uchar data[8]) {

	uchar len = 0;

	if (data[1] == USBASP_FUNC_CONNECT) {

		/* set SCK speed */
		if ((PINC & (1 << PC2)) == 0) {
			ispSetSCKOption(USBASP_ISP_SCK_8);
		} else {
			ispSetSCKOption(prog_sck);
		}

		/* set compatibility mode of address delivering */
		prog_address_newmode = 0;

		ledRedOn();
		ispConnect();

	} else if (data[1] == USBASP_FUNC_DISCONNECT) {
		ispDisconnect();
		ledRedOff();

	} else if (data[1] == USBASP_FUNC_TRANSMIT) {
		replyBuffer[0] = ispTransmit(data[2]);
		replyBuffer[1] = ispTransmit(data[3]);
		replyBuffer[2] = ispTransmit(data[4]);
		replyBuffer[3] = ispTransmit(data[5]);
		len = 4;

	} else if (data[1] == USBASP_FUNC_READFLASH) {

		if (!prog_address_newmode)
			prog_address = (data[3] << 8) | data[2];

		prog_nbytes = (data[7] << 8) | data[6];
		prog_state = PROG_STATE_READFLASH;
		len = 0xff; /* multiple in */

	} else if (data[1] == USBASP_FUNC_READEEPROM) {

		if (!prog_address_newmode)
			prog_address = (data[3] << 8) | data[2];

		prog_nbytes = (data[7] << 8) | data[6];
		prog_state = PROG_STATE_READEEPROM;
		len = 0xff; /* multiple in */

	} else if (data[1] == USBASP_FUNC_ENABLEPROG) {
		replyBuffer[0] = ispEnterProgrammingMode();
		len = 1;

	} else if (data[1] == USBASP_FUNC_WRITEFLASH) {

		if (!prog_address_newmode)
			prog_address = (data[3] << 8) | data[2];

		prog_pagesize = data[4];
		prog_blockflags = data[5] & 0x0F;
		prog_pagesize += (((unsigned int) data[5] & 0xF0) << 4);
		if (prog_blockflags & PROG_BLOCKFLAG_FIRST) {
			prog_pagecounter = prog_pagesize;
		}
		prog_nbytes = (data[7] << 8) | data[6];
		prog_state = PROG_STATE_WRITEFLASH;
		len = 0xff; /* multiple out */

	} else if (data[1] == USBASP_FUNC_WRITEEEPROM) {

		if (!prog_address_newmode)
			prog_address = (data[3] << 8) | data[2];

		prog_pagesize = 0;
		prog_blockflags = 0;
		prog_nbytes = (data[7] << 8) | data[6];
		prog_state = PROG_STATE_WRITEEEPROM;
		len = 0xff; /* multiple out */

	} else if (data[1] == USBASP_FUNC_SETLONGADDRESS) {

		/* set new mode of address delivering (ignore address delivered in commands) */
		prog_address_newmode = 1;
		/* set new address */
		prog_address = *((unsigned long*) &data[2]);

	} else if (data[1] == USBASP_FUNC_SETISPSCK) {

		/* set sck option */
		prog_sck = data[2];
		replyBuffer[0] = 0;
		len = 1;

	} else if (data[1] == USBASP_FUNC_TPI_CONNECT) {
		tpi_dly_cnt = data[2] | (data[3] << 8);

		/* RST high */
		ISP_OUT |= (1 << ISP_RST);
		ISP_DDR |= (1 << ISP_RST);

		clockWait(3);

		/* RST low */
		ISP_OUT &= ~(1 << ISP_RST);
		ledRedOn();

		clockWait(16);
		tpi_init();
	
	} else if (data[1] == USBASP_FUNC_TPI_DISCONNECT) {

		tpi_send_byte(TPI_OP_SSTCS(TPISR));
		tpi_send_byte(0);

		clockWait(10);

		/* pulse RST */
		ISP_OUT |= (1 << ISP_RST);
		clockWait(5);
		ISP_OUT &= ~(1 << ISP_RST);
		clockWait(5);

		/* set all ISP pins inputs */
		ISP_DDR &= ~((1 << ISP_RST) | (1 << ISP_SCK) | (1 << ISP_MOSI));
		/* switch pullups off */
		ISP_OUT &= ~((1 << ISP_RST) | (1 << ISP_SCK) | (1 << ISP_MOSI));

		ledRedOff();
	
	} else if (data[1] == USBASP_FUNC_TPI_RAWREAD) {
		replyBuffer[0] = tpi_recv_byte();
		len = 1;
	
	} else if (data[1] == USBASP_FUNC_TPI_RAWWRITE) {
		tpi_send_byte(data[2]);
	
	} else if (data[1] == USBASP_FUNC_TPI_READBLOCK) {
		prog_address = (data[3] << 8) | data[2];
		prog_nbytes = (data[7] << 8) | data[6];
		prog_state = PROG_STATE_TPI_READ;
		len = 0xff; /* multiple in */
	
	} else if (data[1] == USBASP_FUNC_TPI_WRITEBLOCK) {
		prog_address = (data[3] << 8) | data[2];
		prog_nbytes = (data[7] << 8) | data[6];
		prog_state = PROG_STATE_TPI_WRITE;
		len = 0xff; /* multiple out */
	
	} else if (data[1] == USBASP_FUNC_GETCAPABILITIES) {
		replyBuffer[0] = USBASP_CAP_0_TPI;
		replyBuffer[1] = 0;
		replyBuffer[2] = 0;
		replyBuffer[3] = 0;
		len = 4;
	}

	usbMsgPtr = replyBuffer;

	return len;
}

uchar usbFunctionRead(uchar *data, uchar len) {

	uchar i;

	/* check if programmer is in correct read state */
	if ((prog_state != PROG_STATE_READFLASH) && (prog_state
			!= PROG_STATE_READEEPROM) && (prog_state != PROG_STATE_TPI_READ)) {
		return 0xff;
	}

	/* fill packet TPI mode */
	if(prog_state == PROG_STATE_TPI_READ)
	{
		tpi_read_block(prog_address, data, len);
		prog_address += len;
		return len;
	}

	/* fill packet ISP mode */
	for (i = 0; i < len; i++) {
		if (prog_state == PROG_STATE_READFLASH) {
			data[i] = ispReadFlash(prog_address);
		} else {
			data[i] = ispReadEEPROM(prog_address);
		}
		prog_address++;
	}

	/* last packet? */
	if (len < 8) {
		prog_state = PROG_STATE_IDLE;
	}

	return len;
}

uchar usbFunctionWrite(uchar *data, uchar len) {

	uchar retVal = 0;
	uchar i;

	/* check if programmer is in correct write state */
	if ((prog_state != PROG_STATE_WRITEFLASH) && (prog_state
			!= PROG_STATE_WRITEEEPROM) && (prog_state != PROG_STATE_TPI_WRITE)) {
		return 0xff;
	}

	if (prog_state == PROG_STATE_TPI_WRITE)
	{
		tpi_write_block(prog_address, data, len);
		prog_address += len;
		prog_nbytes -= len;
		if(prog_nbytes <= 0)
		{
			prog_state = PROG_STATE_IDLE;
			return 1;
		}
		return 0;
	}

	for (i = 0; i < len; i++) {

		if (prog_state == PROG_STATE_WRITEFLASH) {
			/* Flash */

			if (prog_pagesize == 0) {
				/* not paged */
				ispWriteFlash(prog_address, data[i], 1);
			} else {
				/* paged */
				ispWriteFlash(prog_address, data[i], 0);
				prog_pagecounter--;
				if (prog_pagecounter == 0) {
					ispFlushPage(prog_address, data[i]);
					prog_pagecounter = prog_pagesize;
				}
			}

		} else {
			/* EEPROM */
			ispWriteEEPROM(prog_address, data[i]);
		}

		prog_nbytes--;

		if (prog_nbytes == 0) {
			prog_state = PROG_STATE_IDLE;
			if ((prog_blockflags & PROG_BLOCKFLAG_LAST) && (prog_pagecounter
					!= prog_pagesize)) {

				/* last block and page flush pending, so flush it now */
				ispFlushPage(prog_address, data[i]);
			}

			retVal = 1; // Need to return 1 when no more data is to be received
		}

		prog_address++;
	}

	return retVal;
}

int main(void) {
	uchar i, j;

	/* no pullups on USB and ISP pins */
	PORTD = 0;
	PORTB = 0;
	/* all outputs except PD2 = INT0 */
	DDRD = ~(1 << 2);

	/* output SE0 for USB reset */
	DDRB = ~0;
	j = 0;
	/* USB Reset by device only required on Watchdog Reset */
	while (--j) {
		i = 0;
		/* delay >10ms for USB reset */
		while (--i)
			;
	}
	/* all USB and ISP pins inputs */
	DDRB = 0;

	/* all inputs except PC0, PC1 */
	DDRC = 0x03;
	PORTC = 0xfe;

	/* init timer */
	clockInit();

	/* main event loop */
	usbInit();
	sei();
	for (;;) {
		usbPoll();
	}
	return 0;
}

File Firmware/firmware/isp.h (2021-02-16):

/*
 * isp.h - part of USBasp
 *
 * Autor..........: Thomas Fischl <tfischl@gmx.de>
 * Description....: Provides functions for communication/programming
 *                  over ISP interface
 * Licence........: GNU GPL v2 (see Readme.txt)
 * Creation Date..: 2005-02-23
 * Last change....: 2009-02-28
 */

#ifndef __isp_h_included__
#define	__isp_h_included__

#ifndef uchar
#define	uchar	unsigned char
#endif

#define	ISP_OUT   PORTB
#define ISP_IN    PINB
#define ISP_DDR   DDRB
#define ISP_RST   PB2
#define ISP_MOSI  PB3
#define ISP_MISO  PB4
#define ISP_SCK   PB5

/* Prepare connection to target device */
void ispConnect();

/* Close connection to target device */
void ispDisconnect();

/* read an write a byte from isp using software (slow) */
uchar ispTransmit_sw(uchar send_byte);

/* read an write a byte from isp using hardware (fast) */
uchar ispTransmit_hw(uchar send_byte);

/* enter programming mode */
uchar ispEnterProgrammingMode();

/* read byte from eeprom at given address */
uchar ispReadEEPROM(unsigned int address);

/* write byte to flash at given address */
uchar ispWriteFlash(unsigned long address, uchar data, uchar pollmode);

uchar ispFlushPage(unsigned long address, uchar pollvalue);

/* read byte from flash at given address */
uchar ispReadFlash(unsigned long address);

/* write byte to eeprom at given address */
uchar ispWriteEEPROM(unsigned int address, uchar data);

/* pointer to sw or hw transmit function */
uchar (*ispTransmit)(uchar);

/* set SCK speed. call before ispConnect! */
void ispSetSCKOption(uchar sckoption);

/* load extended address byte */
void ispLoadExtendedAddressByte(unsigned long address);

#endif /* __isp_h_included__ */

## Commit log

2021-02-17 devBoard, gerbers
    [USBaspProgrammer_Thomas-Fischl.kicad_pcb, devBoard.kicad_pcb, devBoard.sch]
2021-02-18 New PCBs
    [USBaspProgrammer_Thomas-Fischl.kicad_pcb, devBoard-0.1.kicad_pcb, devBoard.kicad_pcb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]
2021-02-20 dev board
    [ATmega328ProgrammerBoard.fzz]
2022-03-04 new kicad version
    [USBaspProgrammer_Thomas-Fischl.kicad_pcb, USBaspProgrammer_Thomas-Fischl.kicad_sch]
2022-03-04 kicad 6
    [devBoard.kicad_pcb, devBoard.kicad_sch]
2022-03-19 new dev board
    [devBoardv2.kicad_pcb, devBoardv2.kicad_sch, t3001.kicad_pcb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]
2025-01-10 workspace file
    [USBaspProgrammer-2in1.kicad_pcb, USBaspProgrammer-2in1.kicad_sch, dev_board.kicad_sch]
2025-01-29 schematics and pcb
    [USBaspProgrammer-2in1.kicad_pcb, USBaspProgrammer-2in1.kicad_sch, dev_board.kicad_sch]
